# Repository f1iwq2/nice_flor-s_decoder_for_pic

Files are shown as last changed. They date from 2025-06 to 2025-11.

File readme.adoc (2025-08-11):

Nice flor-s / Came / CARDIN S449 / Somfy RTS / EV1527 /PT2260 remote decoder receiver for pic
=============================================================================================

Programme pic pour décoder les protocoles des télécommandes Nice-florS, CAME, EV1527, PT2260, Cardin S449 et Somfy RTS.
Fobloqs n'est pas terminé.
Le projet est composé d'un PIC 18F26K80 à 16 MHz (x4 par pll = 64 MHz)
L'eprom interne contient le fichier ki.bin ainsi que les télécommandes apprises.
L'eprom externe de 128Ko contient le fichier codes.bin
Le platine électronique est faite en Kicad, répertoire "telecommande".
Le logiciel est fait avec MPLAB XIDE, repertoire "telecommande.X".
Utiliser la directive francais pour basculer en français pour le dialogues UART (230400 bauds par défaut)
Came utilise le protocole radio OOK, code fixe.
NiceFlorS utilise le protocole radio ASK, code roulant.
Cardin utilise le protocole radio FSK, code roulant.
Utilisez le récepteur adéquat. Ne brancher qu'un seul récepteur sur la platine.
RXB6, RFM210LCF-A = ASK et OOK.
RXB15 = FSK
documentation dans le fichier pdf.

Taper ? [enter] dans le terminal pour afficher le menu.

Pic program to decode Nice-florS, CAME, EV1527, Cardin S449, and SOMFY RTS remote devices.
Fobloqs is not completed.
This project is made with a PIC 18F26K80 at 16 MHz (x4 with pll = 64 MHz)
Internal eprom contains the ki.bin file, and also learnt remotes.
External 128Kb eprom contains codes.bin file. 
The electronic board is made with Kicad, "telecommande" directory.
The software is made with MPLAB XIDE, "telecommande.X" directory.
Use english directive to switch to english UART dialogs (230400 bauds default).

CAME use OOK radio protocol. 
NiceFlorS use ASK radio protocol, rolling code.
Cardin use FSK radio protocol
Use the correct receiver. Plug only a single receiver on the board.
RXB6, RFM210LCF-A = ASK and OOK.
RXB15 = FSK
Documentation in pdf file.

Type in ? [enter] to display the menu.

The projet a été inspiré par :
This project was inspired from :
https://github.com/Jev1337/NiceFlor-Encoder

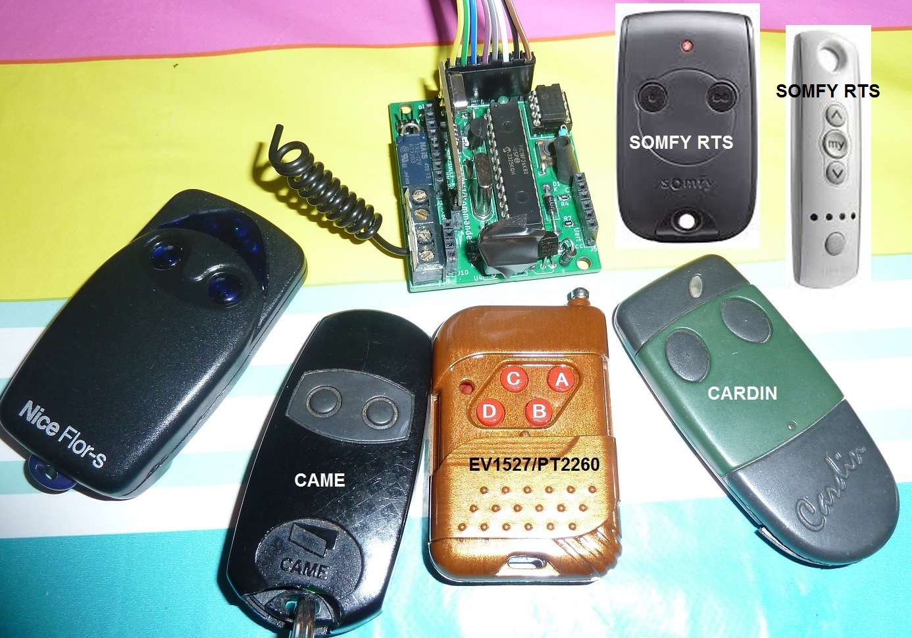
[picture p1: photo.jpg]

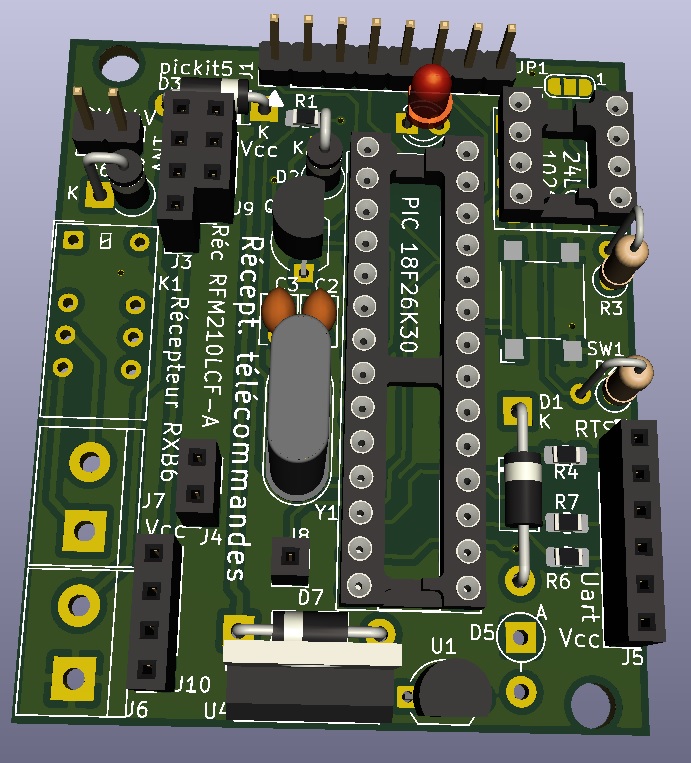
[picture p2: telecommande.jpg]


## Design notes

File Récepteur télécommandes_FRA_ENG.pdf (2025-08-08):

# Documentation carte récepteur télécommandes

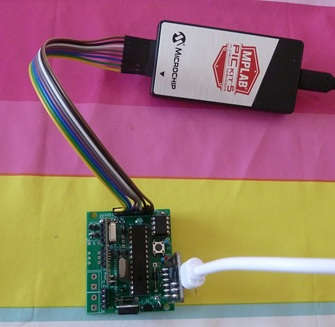
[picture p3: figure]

Cette carte est un décodeur multi protocoles de télécommandes. Elle supporte plusieurs types de récepteurs. Ne monter qu’un récepteur à la fois.

Protocoles OOK ASK (AM) supportés :
Nice Flor S
Came
Somfy RTS
EV/RT/FP 1527
SCT/PT 2260

Protocoles FM FSK:
Cardin S449.
Fobloqs non finalisé.

Carte en test avec le programmateur Pickit5 et le convertisseur USB/UART TTL pour le terminal.

En bas : carte avec le récepteur Dickert HQFM433P-50, et un câble d’adaptation. Rouge=5V, Noir=0V, Vert=Signal RX.

Cette carte décode les protocoles des télécommandes ci-dessus. Elle reçoit le récepteur depuis une carte d’adaptation enfichée sur un support, ou elle permet l’enfichage direct des récepteurs suivants :
Récepteurs testés :

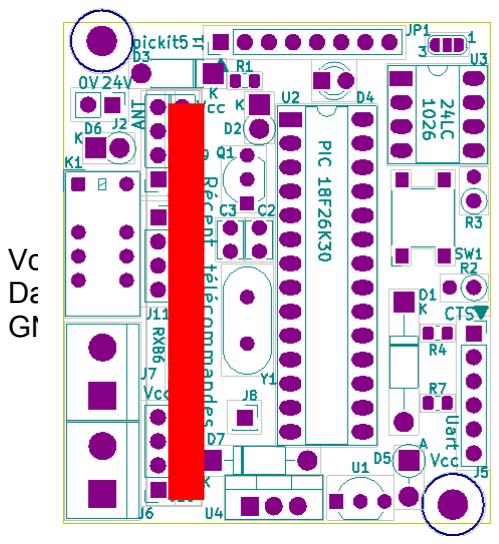
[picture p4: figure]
Data GND

ANT
GND
5V

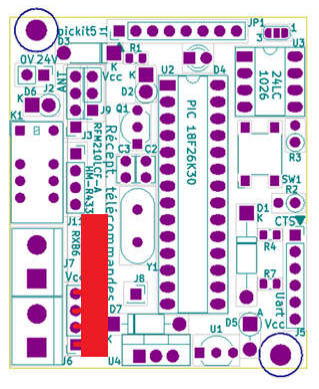
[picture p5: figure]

RX500
Sur connecteur J10
OOK et ASK
fonctionnel

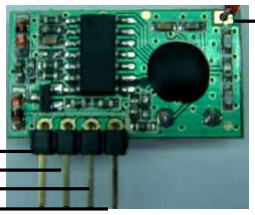
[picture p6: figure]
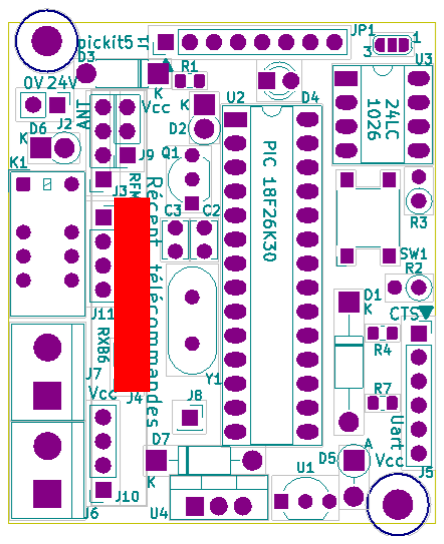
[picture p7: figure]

HM-R-433 sur connecteur J11

Nécessite un reset après mise sous tension
Non fonctionnel
Vcc
Data
GND
Enable

RFM210LCF-A
RXB8 (315 MHz)
sur connecteurs J4 et J9.
fonctionnel
ANT
GND

RXB6 sur connecteurs J3 et J10 OOK ASK
Fonctionnel

ANT

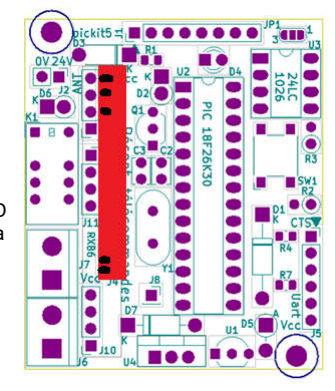
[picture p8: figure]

GND
Data
Vcc

Vcc

Dickert HQFM433P-50

Récepteur FM pour Cardin S449 ou Fobloqs. (35€). Nécessite un câble adaptateur.

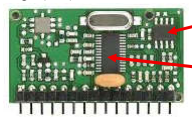
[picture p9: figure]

Nécessite une platine ou un câble d’adaptation.

## Gestion des télécommandes

Pour ajouter une télécommande, appuyer de façon impulsionnelle sur le bouton SW1, et activer une télécommande. La led clignote si la télécommande est reconnue, et le terminal affiche :

Télécommande xxxx ajoutée
Xxxx est le numéro de série renvoyé par la télécommande. Si la commande est déjà enregistrée, le terminal affiche :

Télécommande déjà stockée.

Pour supprimer toutes les télécommandes, appuyer et maintenir le bouton 2s, la led s’allume pendant 2s et s’éteint : toutes les télécommandes ont été supprimées. Le terminal affiche :

Effacement de toutes les télécommandes.

Lorsqu’une télécommande est reconnue, elle colle le relais K1 pendant 1 s. Le protocole des télécommandes est reconnu automatiquement.

Les télécommandes Somfy (certaines) et Cardin ont un bouton de programmation qui permettent de mémoriser un bouton d'une télécommande déja connue à un récepteur associé. Ce programme utilise cette fonction, mais prend en compte tout signal suivant se présentant et peut constituer une faille de sécurité. Cette fonctionnalité peut être dévalidée. Ceci est utile si le récepteur est encastré et on ne peut pas appuyer sur le bouton d'ajout d'une nouvelle télécommande (modeProg).

Schéma fait sous KICAD

Environnement logiciel sous MPLABX 6.25

Ressources internes :

1 Uart à 230240 bauds ou 9600 bauds (pour le transfert des fichiers EPROM en xmodem crc)
1 I2C pour l’eprom 24LC1026
Processeur PIC 18F26K80 à 64 MHz (quartz 16 Mhz ×4)
Le processeur est programmable via l’interface ICSP sur le connecteur J1 qui reçoit le programmateur pickit
5. Le montage peut être alimenté par le pickit.

1 2 3 4 5 6 7 8 9 10 12 13 15

1 : 5v
2,7,11 : GND
3 : Antenne
4,5,6 : NC
10,12,15 : à relier au 5v
13 : PDO (peak detector output) 14 : sortie données

393
EF625

TDA5210

## Utilisation du terminal

Pour utiliser le terminal, il faut brancher un convertisseur UART TTL 5V vers USB comme le WV21443 sur le connecteur J5. Il est connectable point à point. Le protocole RTS/CTS n’est pas utilisé.

WV21443
La vitesse par défaut du terminal est 230240 bauds.

Remote receiver for Nice FLOR-s / CAME / Somfy RTS F1IWQ 2025
** MENU **

?....Affiche ce menu
1....Change mode debug
2....UART9600/230400 bauds
3....Envoyer à l'eprom ext le fichier 128Ko de codes NiceFlorS (protocole Xmodem CRC) 4....Envoyer à l'eprom int le fichier 256o de ki NiceFlorS (protocole Xmodem CRC) 5....Affiche télégramme reçu de la télécommande
6....Affiche la dernière erreur
7....Octets recus par xmodem
8....Affiche les 200 premiers octets de l'EPROM externe 9....Affiche EPROM interne
A....Vérifie checksum eprom ext
B....Lit les 64Ko de l'eprom ext (long) par bloc de 128 octets C....Liste des télécommandes connues

1 : Change le niveau de debug de 0 à 3, pour un affichage plus ou moins détaillé.
2 : Bascule la valeur de l’UART à 230400 ou 9600 bauds. 9600 bauds est à utiliser pour les transferts xmodem. 3 : Envoie le fichier codes.bin à l’eprom externe en protocole xmodem crc (durée env 20mn)
4 : Envoie le fichier ki.bin à l’eprom interne en protocole xmodem crc.
Pour ces options 3 et 4, le caractère C est utilisé pour synchroniser le départ de xmodem. Vous avez 30 secondes pour sélectionner le fichier à envoyer. On peut utiliser teraterm par exemple.
L’écriture des eprom n’est a faire qu’une seule fois. Après l’écriture de l’eprom interne, il est conseillé de ponter les bornes 1 et 2 de JP1 pour éviter une écriture accidentelle.
5. Affiche le dernier télégramme reçu de la télécommande :

NbreBits=150 Protocole Cardin
1 | 33048 17 | 845 | 33 | 1553 | 49 | 1544 | 65 | 765 | 81 | 1233 | 97 | 497
2 | 1037 18 | 759 | 34 | 898 | 50 | 905 | 66 | 1627 | 82 | 383 | 98 | 270
3 | 601 | 19 | 854 | 35 | 1500 | 51 | 1492 | 67 | 805 | 83 | 862 | 99 | 447
4 | 952 | 20 | 752 | 36 | 934 | 52 | 941 | 68 | 1601 | 84 | 1067 100 | 429
5 | 688 | 21 | 859 | 37 | 1469 | 53 | 1464 | 69 | 2029 | 85 | 382 101 | 1011
6 | 888 | 22 | 749 | 38 | 962 | 54 | 965 | 70 | 330 | 86 | 155 102 | 174
7 | 741 | 23 | 859 | 39 | 1448 | 55 | 683 | 71 | 1264 | 87 | 1386 103 | 284
8 | 845 | 24 | 8792 | 40 | 986 | 56 | 1695 | 72 | 76 | 88 | 529 104 | 219
9 | 779 | 25 | 985 | 41 | 1421 | 57 | 748 | 73 | 838 | 89 | 204 105 | 288
10 | 817 | 26 | 1462 | 42 | 991 | 58 | 1643 | 74 | 686 | 90 | 222 106 | 226
11 | 805 | 27 | 930 | 43 | 1424 | 59 | 791 | 75 | 1076 | 91 | 184 107 | 906
12 | 794 | 28 | 1499 | 44 | 996 | 60 | 1607 | 76 | 1013 | 92 | 433 108 | 72
13 | 824 | 29 | 902 | 45 | 657 | 61 | 820 | 77 | 865 | 93 | 2105 109 | 739
14 | 775 | 30 | 1523 | 46 | 1713 | 62 | 1590 | 78 | 157 | 94 | 70 110 | 236
15 | 838 | 31 | 1634 | 47 | 735 | 63 | 1585 | 79 | 226 | 95 | 645 111 | 185
16 | 767 | 32 | 830 | 48 | 1650 | 64 | 868 | 80 | 535 | 96 | 333 112 | 254
Les bits sont en fait les durées des créneaux reçus du signal de la télécommande. La durée est à diviser par 2 pour les convertir en µs.
6. Affiche la dernière erreur du protocole xmodem crc.
7. Affiche les 128 octets reçus du protocole xmodem crc.
8. Affiche les 200 premiers octets de l’eprom externe pour vérification.

Vcc
GND
J5 | RX
| TX
| CTS
| RTS

9. Affiche le contenu de toute l’eprom interne.
A. Vérifie le checksum et le contenu de l’eprom externe.
B. Affiche le contenu de toute l’eprom externe (long).
C. Liste les télécommandes mémorisées.

# Remote control receiver board documentation

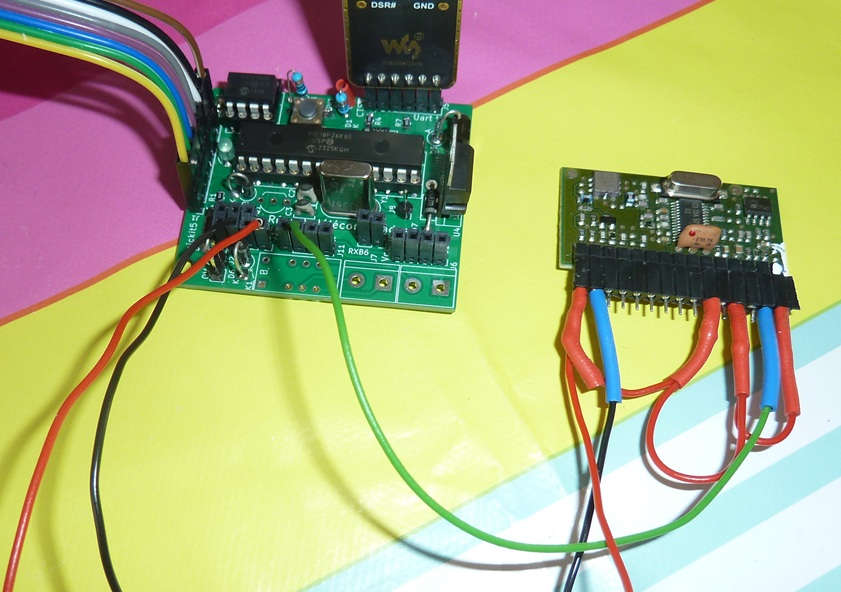
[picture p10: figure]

This board is a multi-protocol remote control decoder. It supports multiple receiver types. Only install one receiver at a time.

OOK ASK (AM) managed protocols :
Nice Flor S
Came
Somfy RTS
EV/RT/FP 1527
SCT/PT 2260

FM FSK protocols :
Cardin S449.
Fobloqs non finalisé.

Board testing with Pickit5 programmer and the USB/UART TTL converter for terminal.

Bottom: Board with Dickert HQFM433P-50 receiver, and adapter cable. Red=5V, Black=0V, Green=RX signal.

This board decodes the protocols of the above remote controls. It receives the bits stream from an adapter receiver board plugged into a support, or direct plugging if using the following receivers:

Tested receivers :

ANT
GND
5V

Dickert HQFM433P-50 (35€)

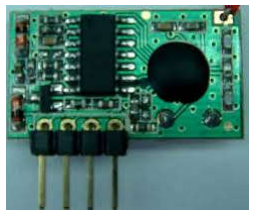
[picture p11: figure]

FM receiver for Cardin S449 or Fobloqs. Needs an adapter ribbon cable.

Electrical drawing with KICAD

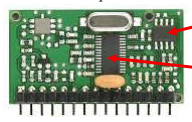
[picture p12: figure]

Software environment with MPLABX 6.25

1 Uart at 230240 bauds or 9600 bauds (for transferring EPROM files with xmodem crc) 1 I2C for eprom 24LC1026
Processor PIC 18F26K80 at 64 MHz (quartz 16 Mhz ×4)

1 2 3 4 5 6 7 8 9 10 12 13 15

1 : 5v
2,7,11 : GND
3 : Antenna
4,5,6 : NC
10,12,15 : needs a bridge to 5v 13 : PDO (peak detector output) 14 : data output

393
EF625

TDA5210

HM-R-433 on connector J11. Requires a reset after power on.

RFM210LCF-A
RXB8 (315 MHz)
on connector J4 and J9.

RXB6 on connectors J3 and J10

## Remote Control Management

To add a remote control, press and hold the SW1 button and press a remote control. The LED flashes if the remote control is recognized, and the terminal displays:

Remote control xxxx added
Xxxx is the serial number returned by the remote control. If the command is already registered, the terminal displays:

Remote control already stored.

To delete all remote controls, press and hold the button for 2 seconds. The LED lights up for 2 seconds and then turns off: all remote controls have been deleted. The terminal displays:

Deleting all remote controls.

When a remote control is recognized, the relay K1 is activated for 1 second. The remote control protocol is automatically recognized.

Some Somfy remotes and Cardin have a programming button that allows to memorize un known button remote to an already linked receiver. This program uses this feature, but also takes into account any subsequent signal that may appear, and might be a security failure. This feature can be disabled. This is useful if the receiver is recessed and the button to add a new remote control can't be pressed.

## Using the Terminal

To use the terminal, you must connect a 5V UART TTL to USB converter such as the WV21443 to the J5 connector. It is a straight connector point-to-point. The RTS/CTS protocol is not used.

WV21443
The terminal default baud rate is 230240.

Remote receiver for Nice FLOR-s / CAME / Somfy RTS F1IWQ 2025
** MENU **

?....Display this menu
1....Change debug mode
2....UART 9600/230400 baud
3....Send the 128KB NiceFlorS code file to the external EPROM (Xmodem CRC protocol) 4....Send the 256KB NiceFlorS code file to the internal EPROM (Xmodem CRC protocol) 5....Display telegram received from the remote control
6....Display the last error
7....Bytes received by Xmodem
8....Display the first 200 bytes of the external EPROM 9....Display the internal EPROM
A....Verify the external EPROM checksum
B....Read the 64KB of the ext (long) EPROM in 128-byte blocks C....List of known remote controls

1: Changes the debug level from 0 to 3, for a more or less detailed display.
2: Toggles the UART value to 230400 or 9600 baud. 9600 baud is to be used for xmodem transfers.

Vcc
GND
J5 | RX
| TX
| CTS
| RTS

3: Sends the codes.bin file to the external EPROM using the xmodem crc protocol (takes approximately 20 minutes).
4: Sends the ki.bin file to the internal EPROM using the xmodem crc protocol.
For options 3 and 4, the C character is used to synchronize the xmodem start. You have 30 seconds to select the file to send. You can use teraterm, for example.
Writing the EPROMs only needs to be done once. After writing the internal EPROM, it is recommended to bridge terminals 1 and 2 of JP1 to prevent accidental writing.
5. Displays the last telegram received from the remote control:

NbreBits=150 Protocole Cardin
1 | 33048 17 | 845 | 33 | 1553 | 49 | 1544 | 65 | 765 | 81 | 1233 | 97 | 497
2 | 1037 18 | 759 | 34 | 898 | 50 | 905 | 66 | 1627 | 82 | 383 | 98 | 270
3 | 601 | 19 | 854 | 35 | 1500 | 51 | 1492 | 67 | 805 | 83 | 862 | 99 | 447
4 | 952 | 20 | 752 | 36 | 934 | 52 | 941 | 68 | 1601 | 84 | 1067 100 | 429
5 | 688 | 21 | 859 | 37 | 1469 | 53 | 1464 | 69 | 2029 | 85 | 382 101 | 1011
6 | 888 | 22 | 749 | 38 | 962 | 54 | 965 | 70 | 330 | 86 | 155 102 | 174
7 | 741 | 23 | 859 | 39 | 1448 | 55 | 683 | 71 | 1264 | 87 | 1386 103 | 284
8 | 845 | 24 | 8792 | 40 | 986 | 56 | 1695 | 72 | 76 | 88 | 529 104 | 219
9 | 779 | 25 | 985 | 41 | 1421 | 57 | 748 | 73 | 838 | 89 | 204 105 | 288
10 | 817 | 26 | 1462 | 42 | 991 | 58 | 1643 | 74 | 686 | 90 | 222 106 | 226
11 | 805 | 27 | 930 | 43 | 1424 | 59 | 791 | 75 | 1076 | 91 | 184 107 | 906
12 | 794 | 28 | 1499 | 44 | 996 | 60 | 1607 | 76 | 1013 | 92 | 433 108 | 72
13 | 824 | 29 | 902 | 45 | 657 | 61 | 820 | 77 | 865 | 93 | 2105 109 | 739
14 | 775 | 30 | 1523 | 46 | 1713 | 62 | 1590 | 78 | 157 | 94 | 70 110 | 236
15 | 838 | 31 | 1634 | 47 | 735 | 63 | 1585 | 79 | 226 | 95 | 645 111 | 185
16 | 767 | 32 | 830 | 48 | 1650 | 64 | 868 | 80 | 535 | 96 | 333 112 | 254

The bits are actually the durations of the received signal slots from the remote control. Divide the duration by 2 to convert them to µs.
6. Displays the last error of the xmodem crc protocol.
7. Displays the 128 bytes received from the xmodem crc protocol.
8. Displays the first 200 bytes of the external EPROM for verification.
9. Displays the contents of the entire internal EPROM.
A. Verifies the checksum and contents of the external EPROM.
B. Displays the contents of the entire external EPROM (takes long time).
C. Lists the stored remote controls.

## Chronogrammes

### Flobloqs (FM-FSK) 433,920 MHz

Séquence complète:

3 bits silence de 3400µs | Récepteur utilisé : Dickert HQFM433P-50
19 bits de sync
1 start bit de 1570µs
Codage des bits de données : Keyloq. Bit0=400µs Bit1=800µs.
Présence éventuelle dans les données d’un extra bit de 1200µs à une distance variable du start bit, ou c’est un stop bit.
L’algorithme de décodage est plus ou moins connu mais pas la clé.
1 stop bit de 1200µs
3 bits de silence de 3400µs

### Cardin S449 (FM-FSK) 433,920 MHz

1 créneau de silence de 16520µs | Récepteur utilisé : Dickert HQFM433P-50
11 ou 12 bits de sync
1 créneau start de 4000µs
Codage des 64 bits de données : Keyloq. Bit1=390/785µs Bit0=785/390µs
Le LSB est envoyé en premier. Le numéro de série n’est pas crypté de même que les boutons.

### NiceFlorS (AM-ASK) 433,920 MHz

1 créneau de silence de 18888µs
1 bit de start 1500µs
Codage des 52 bits de données : spécifique. Bit0=500/1000µs Bit1=1000/500µs 1 créneau stop de 1500µs

### CAME (AM-ASK) 433,920 MHz

1 créneau silence de 14845µs
Codage fixe des 12 bits de données : Bit0=320/640µs Bit1=640/320µs
Silence1 | Silence2 Silence3 | 19 sync | start

56 bits de données

Silence | 11 ou 12 sync | start

64 bits de données

S1 | S2 | S3 | 19 sync | start | Bits de données | stop 3xfin
Silence | start | stop

Silence

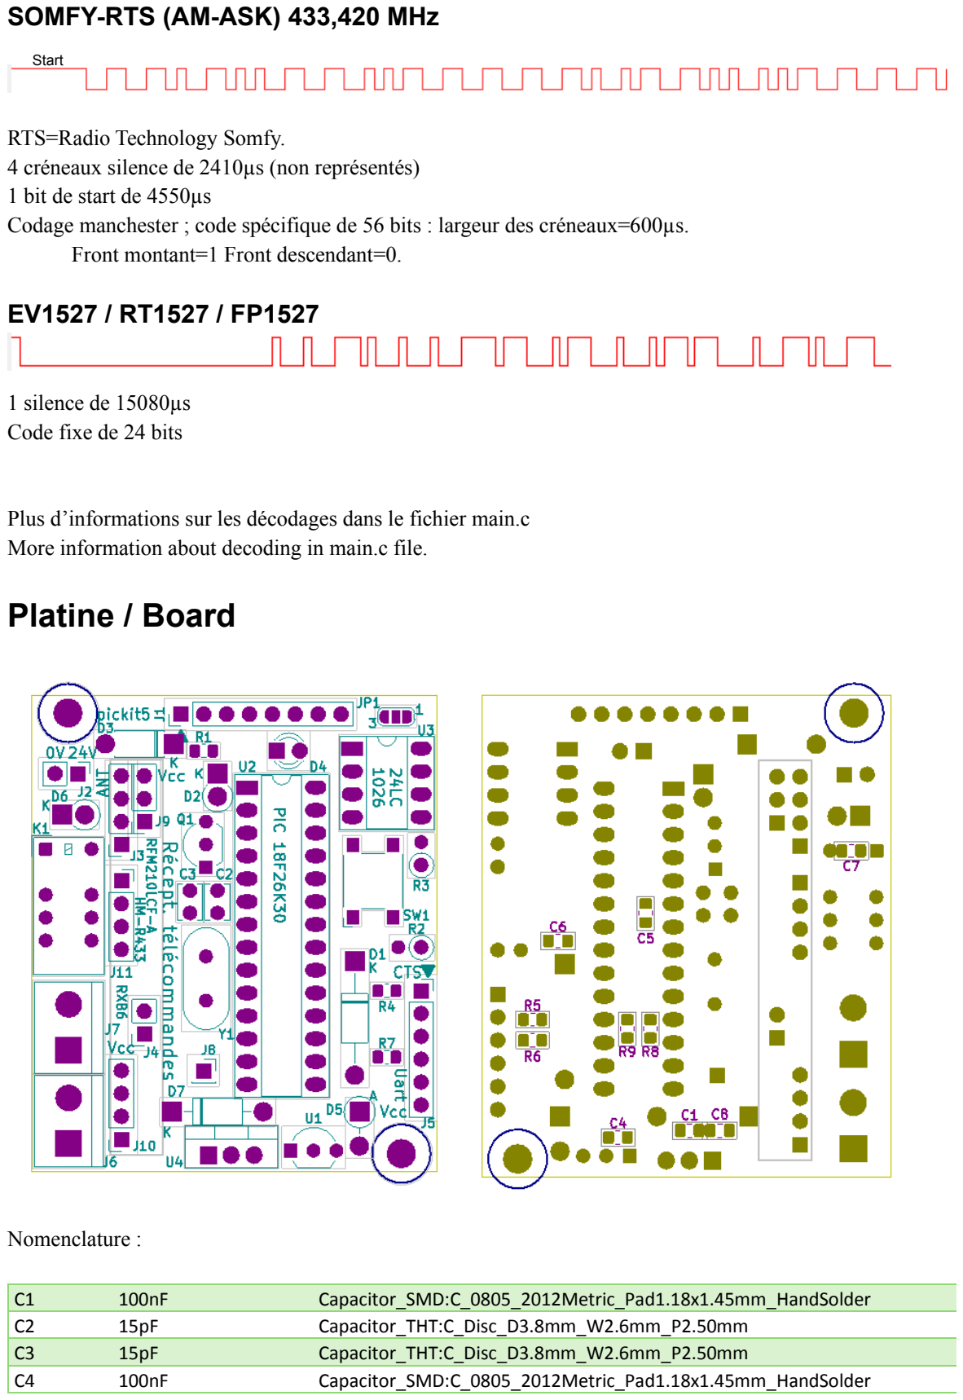
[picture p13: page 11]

### SOMFY-RTS (AM-ASK) 433,420 MHz

RTS=Radio Technology Somfy.
4 créneaux silence de 2410µs (non représentés)
1 bit de start de 4550µs
Codage manchester ; code spécifique de 56 bits : largeur des créneaux=600µs. Front montant=1 Front descendant=0.

### EV1527 / RT1527 / FP1527

1 silence de 15080µs
Code fixe de 24 bits

Plus d’informations sur les décodages dans le fichier main.c More information about decoding in main.c file.

## Platine / Board

Nomenclature :

C1 | 100nF | Capacitor_SMD:C_0805_2012Metric_Pad1.18x1.45mm_HandSolder
C2 | 15pF | Capacitor_THT:C_Disc_D3.8mm_W2.6mm_P2.50mm
C3 | 15pF | Capacitor_THT:C_Disc_D3.8mm_W2.6mm_P2.50mm
C4 | 100nF | Capacitor_SMD:C_0805_2012Metric_Pad1.18x1.45mm_HandSolder

Start

C5 | 100nF | Capacitor_SMD:C_0805_2012Metric_Pad1.18x1.45mm_HandSolder
C6 | 100nF | Capacitor_SMD:C_0805_2012Metric_Pad1.18x1.45mm_HandSolder
C7 | 100nF | Capacitor_SMD:C_0805_2012Metric_Pad1.18x1.45mm_HandSolder
C8 | 100nF | Capacitor_SMD:C_0805_2012Metric_Pad1.18x1.45mm_HandSolder
D1 | 1N4004 | Diode_THT:D_DO-41_SOD81_P12.70mm_Horizontal
D2 | 1N4004 | Diode_THT:D_DO-41_SOD81_P2.54mm_Vertical_KathodeUp
D3 | 1N4004 | Diode_THT:D_DO-41_SOD81_P7.62mm_Horizontal
D4 | LED | LED_THT:LED_D3.0mm
D5 | 1N4004 | Diode_THT:D_DO-41_SOD81_P3.81mm_Vertical_KathodeUp
D6 | 1N4004 | Diode_THT:D_DO-41_SOD81_P2.54mm_Vertical_KathodeUp
D7 | 1N4004 | Diode_THT:D_DO-41_SOD81_P10.16mm_Horizontal
H1 | MountingHole | MountingHole:MountingHole_3.2mm_M3
H2 | MountingHole | MountingHole:MountingHole_3.2mm_M3
J1 | Conn_01x08_Male | Connector_PinHeader_2.54mm:PinHeader_1x08_P2.54mm_Vertical
J10 | Conn_01x04_Female | Connector_PinSocket_2.54mm:PinSocket_1x04_P2.54mm_Vertical
J11 | Conn_01x04_Female | Connector_PinSocket_2.54mm:PinSocket_1x04_P2.54mm_Vertical
J2 | Conn_01x02_Male | Connector_PinHeader_2.54mm:PinHeader_1x02_P2.54mm_Vertical
J3 | Conn_01x04_Female | Connector_PinSocket_2.54mm:PinSocket_1x04_P2.54mm_Vertical
J4 | Conn_01x02_Female | Connector_PinSocket_2.54mm:PinSocket_1x02_P2.54mm_Vertical
J5 | Conn_01x06_Male | Connector_PinSocket_2.54mm:PinSocket_1x06_P2.54mm_Vertical
J6 | Screw_Terminal_01x0
| 2 | TerminalBlock:TerminalBlock_bornier-2_P5.08mm
J7 | Screw_Terminal_01x0
| 2 | TerminalBlock:TerminalBlock_bornier-2_P5.08mm
J8 | Conn_01x01_Male | Connector_PinSocket_2.54mm:PinSocket_1x01_P2.54mm_Vertical
J9 | Conn_01x03_Female | Connector_PinSocket_2.54mm:PinSocket_1x03_P2.54mm_Vertical
JP1 | SolderJumper_3_Open | Jumper:SolderJumper-
| | 3_P1.3mm_Open_RoundedPad1.0x1.5mm_NumberLabels
K1 | ATX203 | Relay_THT:Relay_DPDT_Kemet_EC2 12V coil bobine 12V
Q1 | BS170 | Package_TO_SOT_THT:TO-92_Inline_Wide
R1 | 330 | Resistor_SMD:R_0805_2012Metric_Pad1.20x1.40mm_HandSolder
R2 | 330 | Resistor_THT:R_Axial_DIN0207_L6.3mm_D2.5mm_P2.54mm_Vertical
R3 | 330 | Resistor_THT:R_Axial_DIN0207_L6.3mm_D2.5mm_P2.54mm_Vertical
R4 | 90 | Resistor_SMD:R_0805_2012Metric_Pad1.20x1.40mm_HandSolder
R5 | 90 | Resistor_SMD:R_0805_2012Metric_Pad1.20x1.40mm_HandSolder
R6 | 90 | Resistor_SMD:R_0805_2012Metric_Pad1.20x1.40mm_HandSolder
R7 | 90 | Resistor_SMD:R_0805_2012Metric_Pad1.20x1.40mm_HandSolder
R8 | 8,2k | Resistor_SMD:R_0805_2012Metric_Pad1.20x1.40mm_HandSolder
R9 | 8,2k | Resistor_SMD:R_0805_2012Metric_Pad1.20x1.40mm_HandSolder
Reference | Value | Footprint
SW1 | SW_MEC_5E | Button_Switch_SMD:SW_SPST_Omron_B3FS-101xP
U1 | L78L05_TO92 | Package_TO_SOT_THT:TO-92_Inline_Wide
U2 | PIC18F26K80_ISP | Package_DIP:DIP-28_W7.62mm_Socket_LongPads
U3 | 24LC1026-I_P | Package_DIP:DIP-8_W7.62mm_Socket_LongPads
U4 | 7812 | Package_TO_SOT_THT:TO-220-3_Vertical
Y1 | Crystal 16MHz | Crystal:Crystal_HC18-U_Vertical

## Github contains

https://github.com/f1iwq2/nice_flor-s_decoder_for_pic

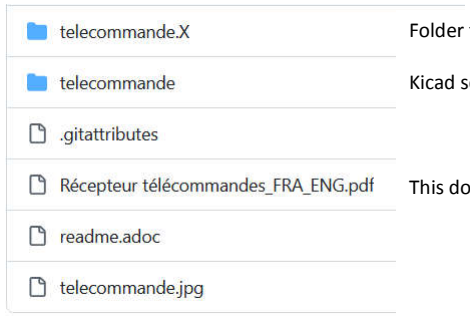
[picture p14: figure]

Folder for PIC soware. Use MPLABX. Main.c is the main.

Kicad schemacs drawings. Sub dir contains gerber files.

This documentaon.

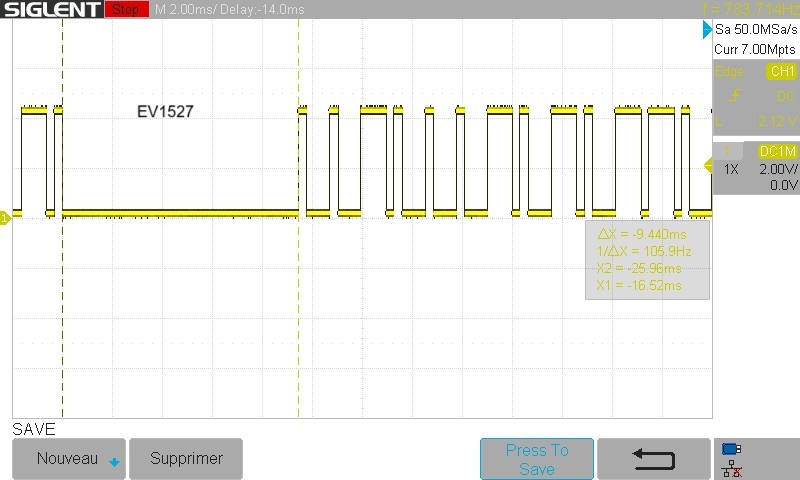
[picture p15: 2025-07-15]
telecommande.X/EV1527-1.jpg

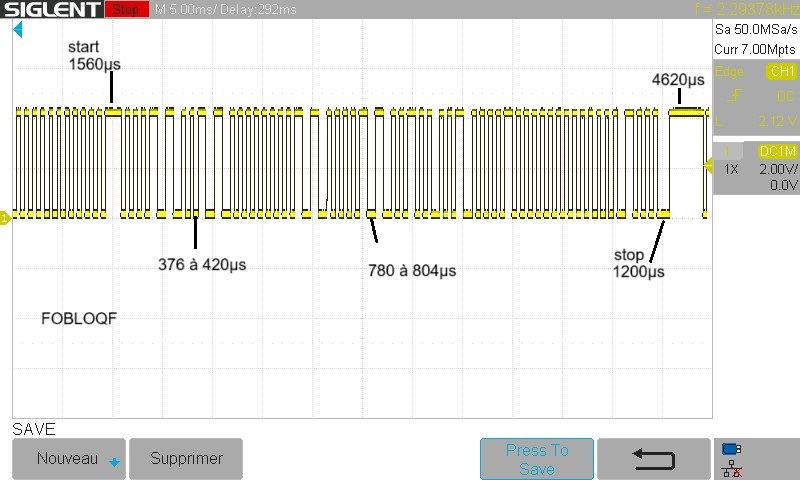
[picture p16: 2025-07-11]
telecommande.X/fobloqf2.jpg

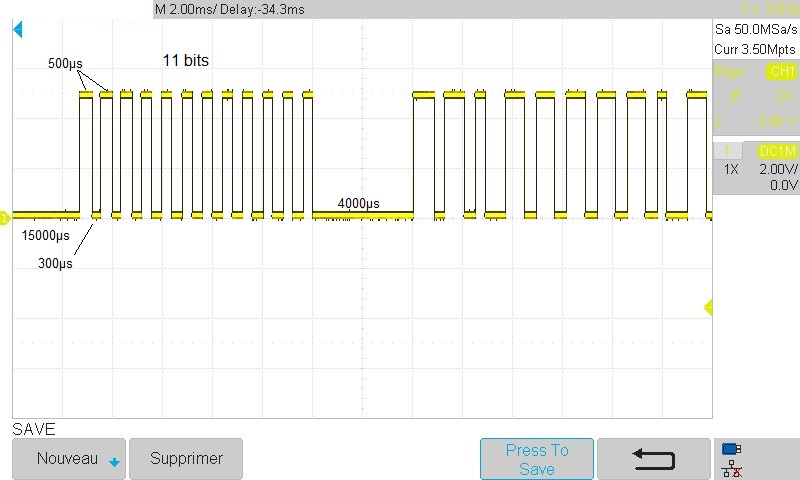
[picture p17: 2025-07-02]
telecommande.X/cardin_debut.jpg

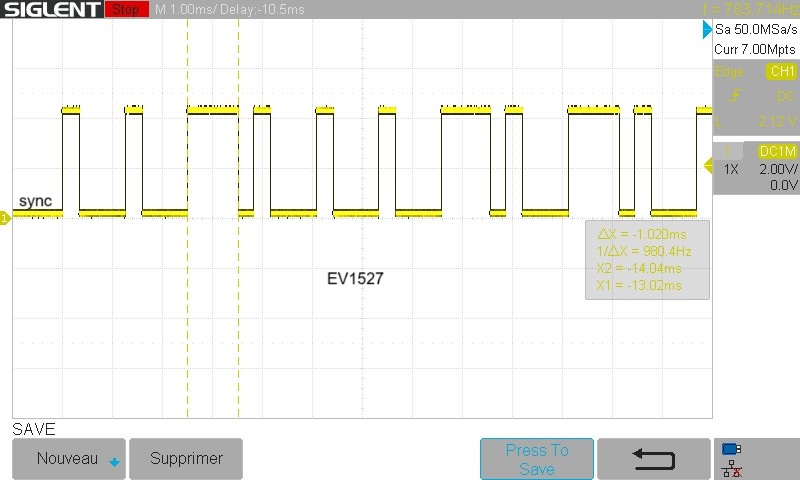
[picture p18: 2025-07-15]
telecommande.X/EV1527-2.jpg

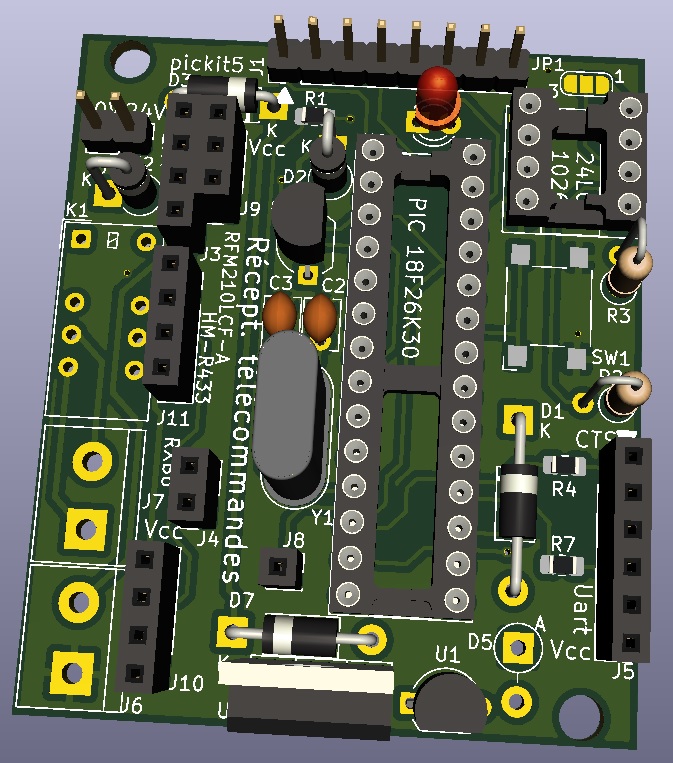
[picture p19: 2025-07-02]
telecommande/telecommande.jpg

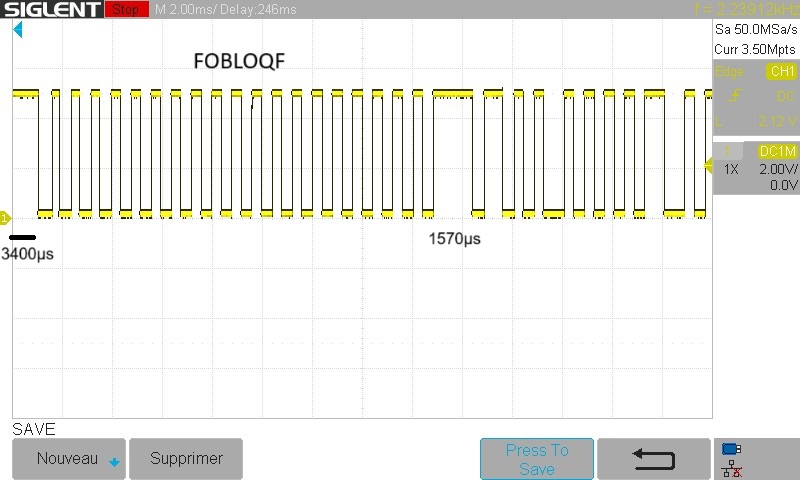
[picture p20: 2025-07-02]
telecommande.X/fobloqf.jpg

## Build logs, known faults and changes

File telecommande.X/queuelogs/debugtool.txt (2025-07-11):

247 1751989909826 GEN4_CONNECT_DIAGNOSTICS:MPLABCommTool is null

247 1751989909826 GEN4_TO_CONTROLLER_LOG:GEN4_CONNECT_INT_LOG_PIC18F26K80 Pre:GetFirmwareInfo
247 1751989909826 GEN4_TO_CONTROLLER_LOG:GEN4_CONNECT_INT_LOG_PIC18F26K80 Payload
247 1751989909826 GEN4_TO_CONTROLLER_LOG:GEN4_CONNECT_INT_LOG_PIC18F26K80 null
247 1751989909826 GEN4_TO_CONTROLLER_LOG:GEN4_CONNECT_INT_LOG_PIC18F26K80 Payload End
247 1751989909827 XXXX 1751989909827, Thread 247: com.Send returned false 
247 1751989909827 XXXX 1751989909827, Thread 247: execCommand: exception after writeSideChanel null 
247 1751989909828 GEN4_CONNECT_DIAGNOSTICS:Removing plug and play observer com.microchip.mplab.mdbcore.RI4Tool.RI4ToolBase$RI4PlugNPlayObserver@26d3e0c3
247 1751989909828 GEN4_CONNECT_DIAGNOSTICS:Begin PlugNPlayObservers list dump:
247 1751989909828 GEN4_CONNECT_DIAGNOSTICS:End PlugNPlayObservers list dump:
247 1751989909881 GEN4_CONNECT_DIAGNOSTICS:Calling RIDbgToolCom.Disconnect
247 1751989909881 GEN4_CONNECT_DIAGNOSTICS:Calling MPLABCommTool.Detach to remove tool from plug and play list
247 1751989909881 GEN4_CONNECT_DIAGNOSTICS:Calling RIDbgToolCom.DisconnectFromMPlabComm
247 1751989909881 GEN4_CONNECT_DIAGNOSTICS:Calling MPLABCommTool.Disconnect
269 1751989937830 GEN4_CONNECT_DIAGNOSTICS:MPLABCommTool is NOT null
269 1751989937830 GEN4_CONNECT_DIAGNOSTICS:AttachedToolPID = 9036, AttachedToolVID = 4d8
269 1751989937830 GEN4_CONNECT_DIAGNOSTICS:transport type = USB
269 1751989937830 GEN4_CONNECT_DIAGNOSTICS:AttachedToolPID = 9036, AttachedToolVID = 4d8
269 1751989937836 com.microchip.mplab.mdbcore.RealICETool.RIDbgToolCom
269 1751989937836 GEN4_CONNECT_DIAGNOSTICS:Before MPLABCommTool.Connect()
269 1751989937837 GEN4_CONNECT_DIAGNOSTICS:After MPLABCommTool.Connect()
269 1751989937837 GEN4_CONNECT_DIAGNOSTICS:Adding new plug and play observer com.microchip.mplab.mdbcore.RI4Tool.RI4ToolBase$RI4PlugNPlayObserver@1160412d
269 1751989937837 GEN4_CONNECT_DIAGNOSTICS:Begin PlugNPlayObservers list dump:
269 1751989937837 GEN4_CONNECT_DIAGNOSTICS:com.microchip.mplab.mdbcore.RI4Tool.RI4ToolBase$RI4PlugNPlayObserver@1160412d
269 1751989937837 GEN4_CONNECT_DIAGNOSTICS:End PlugNPlayObservers list dump:
269 1751989937837 GEN4_CONNECT_DIAGNOSTICS:Registering for alternate PNP notifications. CommPnPCriteria.cPIDList = [9035], CommPnPCriteria.cSerialNumber = 020026702ryn032916

269 1751989937888 GEN4_TO_CONTROLLER_LOG:GEN4_INIT_INT_LOG_PIC18F26K80 Pre:init
269 1751989937888 GEN4_TO_CONTROLLER_LOG:GEN4_INIT_INT_LOG_PIC18F26K80 Payload
269 1751989937888 GEN4_TO_CONTROLLER_LOG:GEN4_INIT_INT_LOG_PIC18F26K80 DeviceInfo: Values:
269 1751989937888 GEN4_TO_CONTROLLER_LOG:GEN4_INIT_INT_LOG_PIC18F26K80 DeviceInfo: pcAddress = 00000ff9, Vpp = 9,00, useRowEraseIfVoltageIsLow = true, voltageBelowWhichUseRowErase = 2,70, deviceName = PIC18F26K80, programmerType = PIC18F
269 1751989937888 GEN4_TO_CONTROLLER_LOG:GEN4_INIT_INT_LOG_PIC18F26K80 DeviceInfo: MemInfo values:
269 1751989937888 GEN4_TO_CONTROLLER_LOG:GEN4_INIT_INT_LOG_PIC18F26K80 DeviceInfo: mask = ffff, exists = true, startAddr = 00000000, endAddr = 0000ffff, rowSize = 0040, rowEraseSize = 0040, addrInc = 0002, widthProgram = 0002
269 1751989937888 GEN4_TO_CONTROLLER_LOG:GEN4_INIT_INT_LOG_PIC18F26K80 DeviceInfo: mask = 00ff, exists = true, startAddr = 00300000, endAddr = 0030000d, rowSize = 0001, rowEraseSize = 0000, addrInc = 0001, widthProgram = 0001
269 1751989937888 GEN4_TO_CONTROLLER_LOG:GEN4_INIT_INT_LOG_PIC18F26K80 DeviceInfo: mask = 0000, exists = false, startAddr = 00000000, endAddr = 00000000, rowSize = 0000, rowEraseSize = 0040, addrInc = 0000, widthProgram = 0000
269 1751989937888 GEN4_TO_CONTROLLER_LOG:GEN4_INIT_INT_LOG_PIC18F26K80 DeviceInfo: mask = 00ff, exists = true, startAddr = 00000000, endAddr = 000003ff, rowSize = 0002, rowEraseSize = 0000, addrInc = 0001, widthProgram = 0001
269 1751989937888 GEN4_TO_CONTROLLER_LOG:GEN4_INIT_INT_LOG_PIC18F26K80 DeviceInfo: mask = 00ff, exists = true, startAddr = 00200000, endAddr = 00200007, rowSize = 0001, rowEraseSize = 0000, addrInc = 0001, widthProgram = 0001
269 1751989937888 GEN4_TO_CONTROLLER_LOG:GEN4_INIT_INT_LOG_PIC18F26K80 DeviceInfo: mask = ffff, exists = true, startAddr = 00200000, endAddr = 002003ff, rowSize = 0040, rowEraseSize = 0040, addrInc = 0002, widthProgram = 0002
269 1751989937888 GEN4_TO_CONTROLLER_LOG:GEN4_INIT_INT_LOG_PIC18F26K80 DeviceInfo: mask = 0000, exists = false, startAddr = 00000000, endAddr = 00000000, rowSize = 0000, rowEraseSize = 0000, addrInc = 0001, widthProgram = 0001
269 1751989937888 GEN4_TO_CONTROLLER_LOG:GEN4_INIT_INT_LOG_PIC18F26K80 DeviceInfo: mask = 0000, exists = false, startAddr = 00000000, endAddr = 00000000, rowSize = 0000, rowEraseSize = 0000, addrInc = 0000, widthProgram = 0000
269 1751989937888 GEN4_TO_CONTROLLER_LOG:GEN4_INIT_INT_LOG_PIC18F26K80 DeviceInfo: mask = 0000, exists = false, startAddr = 00000000, endAddr = 00000000, rowSize = 0000, rowEraseSize = 0000, addrInc = 0000, widthProgram = 0000
269 1751989937888 GEN4_TO_CONTROLLER_LOG:GEN4_INIT_INT_LOG_PIC18F26K80 DeviceInfo: mask = 0000, exists = false, startAddr = 00000000, endAddr = 00000000, rowSize = 0000, rowEraseSize = 0000, addrInc = 0000, widthProgram = 0000
269 1751989937888 GEN4_TO_CONTROLLER_LOG:GEN4_INIT_INT_LOG_PIC18F26K80 DeviceInfo: mask = 0000, exists = false, startAddr = 00000000, endAddr = 00000000, rowSize = 0000, rowEraseSize = 0000, addrInc = 0001, widthProgram = 0001
269 1751989937888 GEN4_TO_CONTROLLER_LOG:GEN4_INIT_INT_LOG_PIC18F26K80 DeviceInfo: mask = 0000, exists = false, startAddr = 00000000, endAddr = 00000000, rowSize = 0000, rowEraseSize = 0000, addrInc = 0001, widthProgram = 0001
269 1751989937888 GEN4_TO_CONTROLLER_LOG:GEN4_INIT_INT_LOG_PIC18F26K80 DeviceInfo: mask = 0000, exists = false, startAddr = 00000000, endAddr = 00000000, rowSize = 0000, rowEraseSize = 0000, addrInc = 0000, widthProgram = 0000
269 1751989937888 GEN4_TO_CONTROLLER_LOG:GEN4_INIT_INT_LOG_PIC18F26K80 DeviceInfo: mask = 0000, exists = false, startAddr = 00000000, endAddr = 00000000, rowSize = 0000, rowEraseSize = 0000, addrInc = 0000, widthProgram = 0000
269 1751989937888 GEN4_TO_CONTROLLER_LOG:GEN4_INIT_INT_LOG_PIC18F26K80 DeviceInfo: mask = 0000, exists = false, startAddr = 00000000, endAddr = 00000000, rowSize = 0000, rowEraseSize = 0000, addrInc = 0000, widthProgram = 0000
269 1751989937888 GEN4_TO_CONTROLLER_LOG:GEN4_INIT_INT_LOG_PIC18F26K80 DeviceInfo: mask = 0000, exists = false, startAddr = 00000000, endAddr = 00000000, rowSize = 0000, rowEraseSize = 0000, addrInc = 0000, widthProgram = 0000
269 1751989937888 GEN4_TO_CONTROLLER_LOG:GEN4_INIT_INT_LOG_PIC18F26K80 DeviceInfo: mask = 7fffffff, exists = true, startAddr = 003ffffe, endAddr = 003fffff, rowSize = 0001, rowEraseSize = 0000, addrInc = 0001, widthProgram = 0001
269 1751989937888 GEN4_TO_CONTROLLER_LOG:GEN4_INIT_INT_LOG_PIC18F26K80 DeviceInfo: mask = 0000, exists = false, startAddr = 00000000, endAddr = 00000000, rowSize = 0000, rowEraseSize = 0000, addrInc = 0000, widthProgram = 0000
269 1751989937888 GEN4_TO_CONTROLLER_LOG:GEN4_INIT_INT_LOG_PIC18F26K80 DeviceInfo: mask = 0000, exists = false, startAddr = 00000000, endAddr = 00000000, rowSize = 0000, rowEraseSize = 0000, addrInc = 0000, widthProgram = 0000
269 1751989937888 GEN4_TO_CONTROLLER_LOG:GEN4_INIT_INT_LOG_PIC18F26K80 DeviceInfo: mask = 0000, exists = false, startAddr = 00000000, endAddr = 00000000, rowSize = 0000, rowEraseSize = 0000, addrInc = 0000, widthProgram = 0000
269 1751989937888 GEN4_TO_CONTROLLER_LOG:GEN4_INIT_INT_LOG_PIC18F26K80 DeviceInfo: mask = 0000, exists = false, startAddr = 00000000, endAddr = 00000000, rowSize = 0000, rowEraseSize = 0000, addrInc = 0000, widthProgram = 0000
269 1751989937888 GEN4_TO_CONTROLLER_LOG:GEN4_INIT_INT_LOG_PIC18F26K80 DeviceInfo: mask = 0000, exists = false, startAddr = 00000000, endAddr = 00000000, rowSize = 0000, rowEraseSize = 0000, addrInc = 0000, widthProgram = 0000
269 1751989937889 GEN4_TO_CONTROLLER_LOG:GEN4_INIT_INT_LOG_PIC18F26K80 DeviceInfo: mask = 0000, exists = false, startAddr = 00000000, endAddr = 00000000, rowSize = 0000, rowEraseSize = 0000, addrInc = 0000, widthProgram = 0000
269 1751989937889 GEN4_TO_CONTROLLER_LOG:GEN4_INIT_INT_LOG_PIC18F26K80 DeviceInfo: CfgRequiredBitsMask Values:
269 1751989937889 GEN4_TO_CONTROLLER_LOG:GEN4_INIT_INT_LOG_PIC18F26K80 Address = 00300000, Mask = 0000005d
269 1751989937889 GEN4_TO_CONTROLLER_LOG:GEN4_INIT_INT_LOG_PIC18F26K80 Address = 00300001, Mask = 000000df
269 1751989937889 GEN4_TO_CONTROLLER_LOG:GEN4_INIT_INT_LOG_PIC18F26K80 Address = 00300002, Mask = 0000007f
269 1751989937889 GEN4_TO_CONTROLLER_LOG:GEN4_INIT_INT_LOG_PIC18F26K80 Address = 00300003, Mask = 0000007f
269 1751989937889 GEN4_TO_CONTROLLER_LOG:GEN4_INIT_INT_LOG_PIC18F26K80 Address = 00300005, Mask = 00000089
269 1751989937889 GEN4_TO_CONTROLLER_LOG:GEN4_INIT_INT_LOG_PIC18F26K80 Address = 00300006, Mask = 00000011
269 1751989937889 GEN4_TO_CONTROLLER_LOG:GEN4_INIT_INT_LOG_PIC18F26K80 Address = 00300008, Mask = 0000000f
269 1751989937889 GEN4_TO_CONTROLLER_LOG:GEN4_INIT_INT_LOG_PIC18F26K80 Address = 00300009, Mask = 000000c0
269 1751989937889 GEN4_TO_CONTROLLER_LOG:GEN4_INIT_INT_LOG_PIC18F26K80 Address = 0030000a, Mask = 0000000f
269 1751989937889 GEN4_TO_CONTROLLER_LOG:GEN4_INIT_INT_LOG_PIC18F26K80 Address = 0030000b, Mask = 000000e0
269 1751989937889 GEN4_TO_CONTROLLER_LOG:GEN4_INIT_INT_LOG_PIC18F26K80 Address = 0030000c, Mask = 0000000f
269 1751989937889 GEN4_TO_CONTROLLER_LOG:GEN4_INIT_INT_LOG_PIC18F26K80 Address = 0030000d, Mask = 00000040
269 1751989937889 GEN4_TO_CONTROLLER_LOG:GEN4_INIT_INT_LOG_PIC18F26K80 BasicInfo: Values:
269 1751989937889 GEN4_TO_CONTROLLER_LOG:GEN4_INIT_INT_LOG_PIC18F26K80 BasicInfo: InputStream = com.microchip.mplab.libs.toolpacksupport.EquatableFileInputStream@b9753464, ToolFlavor = PIC32C
269 1751989937889 GEN4_TO_CONTROLLER_LOG:GEN4_INIT_INT_LOG_PIC18F26K80 Payload End
269 1751989937889 GEN4_TO_CONTROLLER_LOG:GEN4_INIT_INT_LOG_PIC18F26K80 Post:init
269 1751989937889 GEN4_TO_CONTROLLER_LOG:GEN4_INIT_INT_LOG_PIC18F26K80 Return Value
269 1751989937889 GEN4_TO_CONTROLLER_LOG:GEN4_INIT_INT_LOG_PIC18F26K80 none
269 1751989937889 GEN4_TO_CONTROLLER_LOG:GEN4_INIT_INT_LOG_PIC18F26K80 Return End

269 1751989937890 GEN4_TO_CONTROLLER_LOG:GEN4_INIT_INT_LOG_PIC18F26K80 Pre:GetInterfaceProvider
269 1751989937890 GEN4_TO_CONTROLLER_LOG:GEN4_INIT_INT_LOG_PIC18F26K80 Payload
269 1751989937890 GEN4_TO_CONTROLLER_LOG:GEN4_INIT_INT_LOG_PIC18F26K80 RI4DebugInterface
269 1751989937890 GEN4_TO_CONTROLLER_LOG:GEN4_INIT_INT_LOG_PIC18F26K80 Payload End
269 1751989937890 GEN4_TO_CONTROLLER_LOG:GEN4_INIT_INT_LOG_PIC18F26K80 Post:GetInterfaceProvider
269 1751989937890 GEN4_TO_CONTROLLER_LOG:GEN4_INIT_INT_LOG_PIC18F26K80 Return Value
269 1751989937890 GEN4_TO_CONTROLLER_LOG:GEN4_INIT_INT_LOG_PIC18F26K80 com.microchip.mplab.libs.RI4ToolsController.implementations.RI4DebugInterfaceImpl@2580ee27
269 1751989937890 GEN4_TO_CONTROLLER_LOG:GEN4_INIT_INT_LOG_PIC18F26K80 Return End

269 1751989937891 GEN4_TO_CONTROLLER_LOG:GEN4_INIT_INT_LOG_PIC18F26K80 Pre:GetInterfaceProvider
269 1751989937891 GEN4_TO_CONTROLLER_LOG:GEN4_INIT_INT_LOG_PIC18F26K80 Payload
269 1751989937891 GEN4_TO_CONTROLLER_LOG:GEN4_INIT_INT_LOG_PIC18F26K80 RI4ProgramInterface
269 1751989937891 GEN4_TO_CONTROLLER_LOG:GEN4_INIT_INT_LOG_PIC18F26K80 Payload End
269 1751989937891 GEN4_TO_CONTROLLER_LOG:GEN4_INIT_INT_LOG_PIC18F26K80 Post:GetInterfaceProvider
269 1751989937891 GEN4_TO_CONTROLLER_LOG:GEN4_INIT_INT_LOG_PIC18F26K80 Return Value
269 1751989937891 GEN4_TO_CONTROLLER_LOG:GEN4_INIT_INT_LOG_PIC18F26K80 com.microchip.mplab.libs.RI4ToolsController.implementations.RI4ProgramInterfaceImpl@191e8b0a
269 1751989937891 GEN4_TO_CONTROLLER_LOG:GEN4_INIT_INT_LOG_PIC18F26K80 Return End

269 1751989937891 GEN4_TO_CONTROLLER_LOG:GEN4_INIT_INT_LOG_PIC18F26K80 Pre:GetInterfaceProvider
269 1751989937891 GEN4_TO_CONTROLLER_LOG:GEN4_INIT_INT_LOG_PIC18F26K80 Payload
269 1751989937891 GEN4_TO_CONTROLLER_LOG:GEN4_INIT_INT_LOG_PIC18F26K80 RI4ConnectInterface
269 1751989937891 GEN4_TO_CONTROLLER_LOG:GEN4_INIT_INT_LOG_PIC18F26K80 Payload End
269 1751989937891 GEN4_TO_CONTROLLER_LOG:GEN4_INIT_INT_LOG_PIC18F26K80 Post:GetInterfaceProvider
269 1751989937891 GEN4_TO_CONTROLLER_LOG:GEN4_INIT_INT_LOG_PIC18F26K80 Return Value
269 1751989937891 GEN4_TO_CONTROLLER_LOG:GEN4_INIT_INT_LOG_PIC18F26K80 com.microchip.mplab.libs.PK4ToolsController.PK4ConnectInterfaceImpl@a64c82d
269 1751989937891 GEN4_TO_CONTROLLER_LOG:GEN4_INIT_INT_LOG_PIC18F26K80 Return End

269 1751989937891 GEN4_TO_CONTROLLER_LOG:GEN4_INIT_INT_LOG_PIC18F26K80 Pre:GetInterfaceProvider
269 1751989937891 GEN4_TO_CONTROLLER_LOG:GEN4_INIT_INT_LOG_PIC18F26K80 Payload
269 1751989937891 GEN4_TO_CONTROLLER_LOG:GEN4_INIT_INT_LOG_PIC18F26K80 RI4ControllerDiagnosticsInterface
269 1751989937891 GEN4_TO_CONTROLLER_LOG:GEN4_INIT_INT_LOG_PIC18F26K80 Payload End
269 1751989937891 GEN4_TO_CONTROLLER_LOG:GEN4_INIT_INT_LOG_PIC18F26K80 Post:GetInterfaceProvider
269 1751989937891 GEN4_TO_CONTROLLER_LOG:GEN4_INIT_INT_LOG_PIC18F26K80 Return Value
269 1751989937891 GEN4_TO_CONTROLLER_LOG:GEN4_INIT_INT_LOG_PIC18F26K80 com.microchip.mplab.libs.RI4ToolsController.implementations.RI4ControllerDiagnosticsInterfaceImpl@285f19a9
269 1751989937891 GEN4_TO_CONTROLLER_LOG:GEN4_INIT_INT_LOG_PIC18F26K80 Return End

269 1751989937891 GEN4_TO_CONTROLLER_LOG:GEN4_INIT_INT_LOG_PIC18F26K80 Pre:GetInterfaceProvider
269 1751989937891 GEN4_TO_CONTROLLER_LOG:GEN4_INIT_INT_LOG_PIC18F26K80 Payload
269 1751989937891 GEN4_TO_CONTROLLER_LOG:GEN4_INIT_INT_LOG_PIC18F26K80 ProgrammerToGo
269 1751989937891 GEN4_TO_CONTROLLER_LOG:GEN4_INIT_INT_LOG_PIC18F26K80 Payload End
269 1751989937891 GEN4_TO_CONTROLLER_LOG:GEN4_INIT_INT_LOG_PIC18F26K80 Post:GetInterfaceProvider
269 1751989937891 GEN4_TO_CONTROLLER_LOG:GEN4_INIT_INT_LOG_PIC18F26K80 Return Value
269 1751989937891 GEN4_TO_CONTROLLER_LOG:GEN4_INIT_INT_LOG_PIC18F26K80 com.microchip.mplab.libs.RI4ToolsController.implementations.ProgrammerToGoImpl@a8c3b53
269 1751989937891 GEN4_TO_CONTROLLER_LOG:GEN4_INIT_INT_LOG_PIC18F26K80 Return End

269 1751989937892 GEN4_TO_CONTROLLER_LOG:GEN4_INIT_INT_LOG_PIC18F26K80 Pre:GetInterfaceProvider
269 1751989937892 GEN4_TO_CONTROLLER_LOG:GEN4_INIT_INT_LOG_PIC18F26K80 Payload
269 1751989937892 GEN4_TO_CONTROLLER_LOG:GEN4_INIT_INT_LOG_PIC18F26K80 Status
269 1751989937892 GEN4_TO_CONTROLLER_LOG:GEN4_INIT_INT_LOG_PIC18F26K80 Payload End
269 1751989937892 GEN4_TO_CONTROLLER_LOG:GEN4_INIT_INT_LOG_PIC18F26K80 Post:GetInterfaceProvider
269 1751989937892 GEN4_TO_CONTROLLER_LOG:GEN4_INIT_INT_LOG_PIC18F26K80 Return Value
269 1751989937892 GEN4_TO_CONTROLLER_LOG:GEN4_INIT_INT_LOG_PIC18F26K80 null
269 1751989937892 GEN4_TO_CONTROLLER_LOG:GEN4_INIT_INT_LOG_PIC18F26K80 Return End

269 1751989937900 GEN4_TO_CONTROLLER_LOG:GEN4_CONNECT_INT_LOG_PIC18F26K80 Pre:EstablishCommunincations
269 1751989937900 GEN4_TO_CONTROLLER_LOG:GEN4_CONNECT_INT_LOG_PIC18F26K80 Payload
269 1751989937900 GEN4_TO_CONTROLLER_LOG:GEN4_CONNECT_INT_LOG_PIC18F26K80 com.microchip.mplab.mdbcore.PK5Tool.PK5Com@7d38335e
269 1751989937900 GEN4_TO_CONTROLLER_LOG:GEN4_CONNECT_INT_LOG_PIC18F26K80 Payload End
269 1751989937900 GEN4_TO_CONTROLLER_LOG:GEN4_CONNECT_INT_LOG_PIC18F26K80 Post:EstablishCommunincations
269 1751989937900 GEN4_TO_CONTROLLER_LOG:GEN4_CONNECT_INT_LOG_PIC18F26K80 Return Value
269 1751989937900 GEN4_TO_CONTROLLER_LOG:GEN4_CONNECT_INT_LOG_PIC18F26K80 true
269 1751989937900 GEN4_TO_CONTROLLER_LOG:GEN4_CONNECT_INT_LOG_PIC18F26K80 Return End

269 1751989937900 GEN4_TO_CONTROLLER_LOG:GEN4_CONNECT_INT_LOG_PIC18F26K80 Pre:GetFirmwareInfo
269 1751989937900 GEN4_TO_CONTROLLER_LOG:GEN4_CONNECT_INT_LOG_PIC18F26K80 Payload
269 1751989937900 GEN4_TO_CONTROLLER_LOG:GEN4_CONNECT_INT_LOG_PIC18F26K80 null
269 1751989937900 GEN4_TO_CONTROLLER_LOG:GEN4_CONNECT_INT_LOG_PIC18F26K80 Payload End
269 1751989937901 XXXX 1751989937901, Thread 269: com.Send returned false 
269 1751989937901 XXXX 1751989937901, Thread 269: execCommand: exception after writeSideChanel null

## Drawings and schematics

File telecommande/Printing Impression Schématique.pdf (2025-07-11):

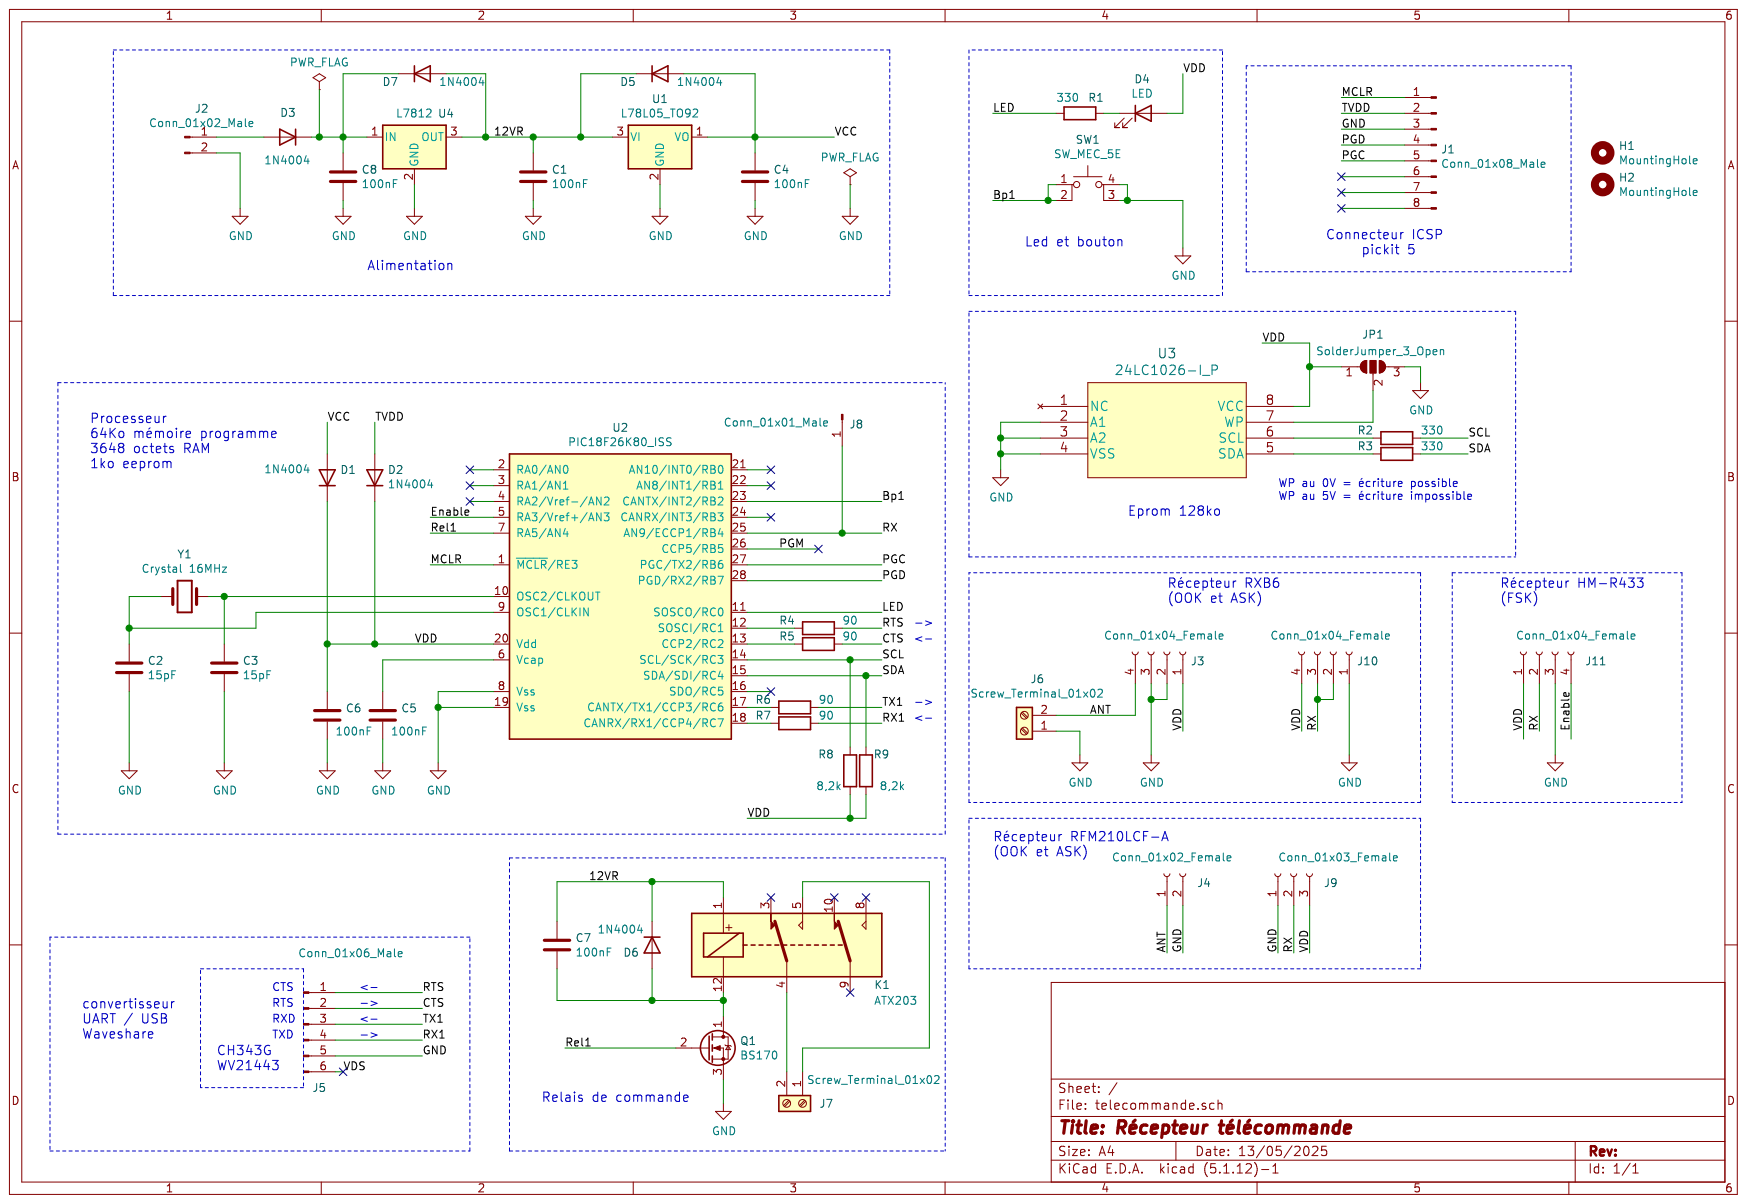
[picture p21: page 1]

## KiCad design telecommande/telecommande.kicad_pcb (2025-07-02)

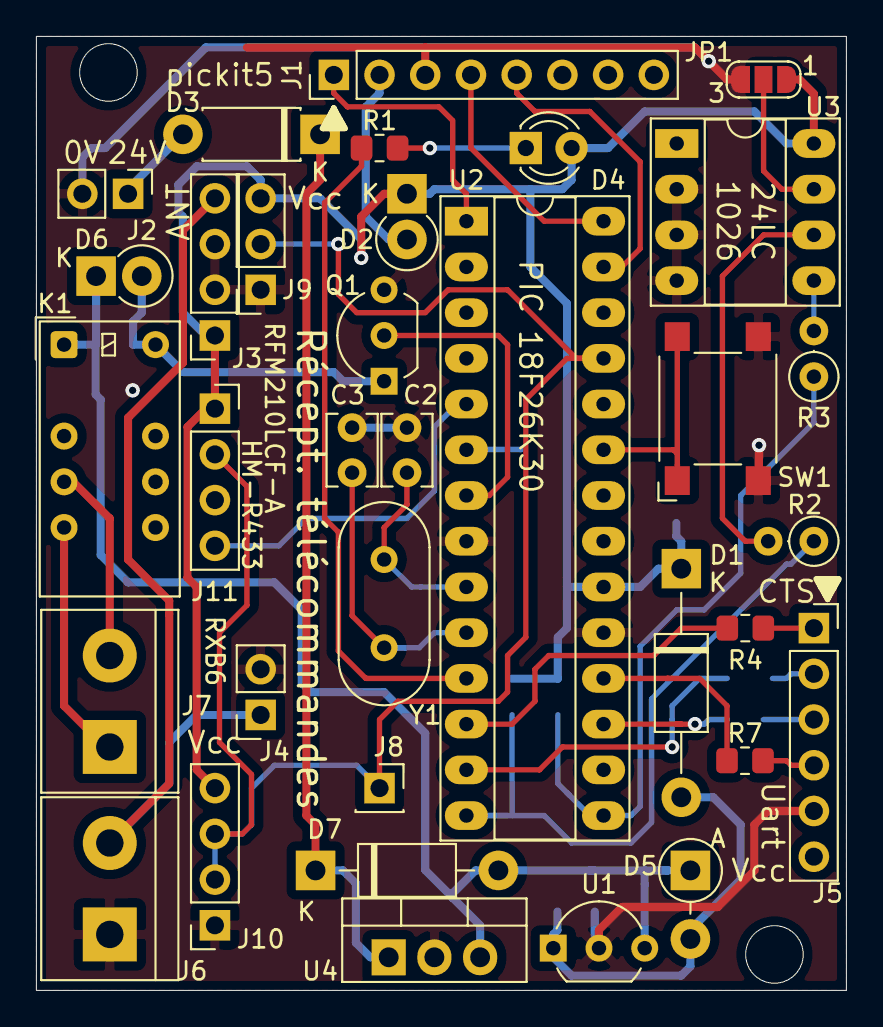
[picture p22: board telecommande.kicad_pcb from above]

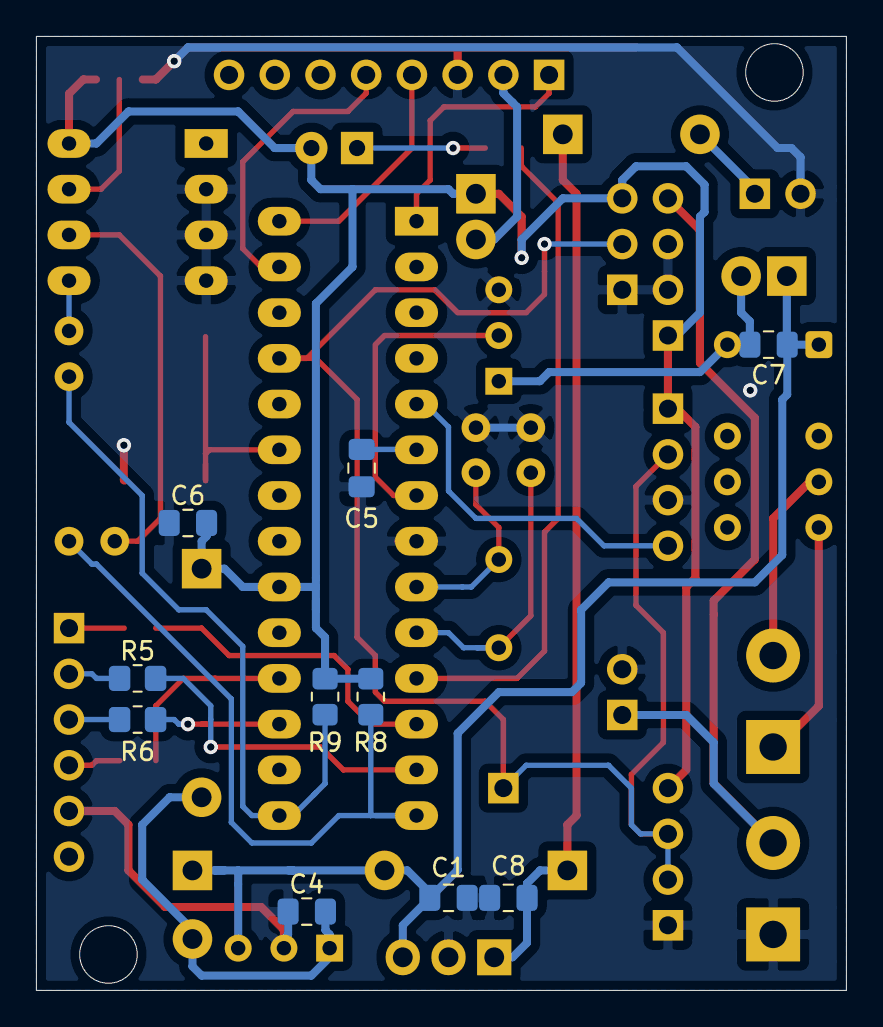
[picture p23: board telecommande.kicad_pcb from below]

Board: 2 copper layers, 45.0 x 53.0 mm, 46 parts (10 on the bottom side), 36 nets.

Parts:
C1, C4, C5, C6, C7, C8: 100nF; C_0805_2012Metric_Pad1.18x1.45mm_HandSolder
C2, C3: 15pF; C_Disc_D3.8mm_W2.6mm_P2.50mm
D1: 1N4004; D_DO-41_SOD81_P12.70mm_Horizontal
D2, D6: 1N4004; D_DO-41_SOD81_P2.54mm_Vertical_KathodeUp
D3: 1N4004; D_DO-41_SOD81_P7.62mm_Horizontal
D4: LED; LED_D3.0mm
D5: 1N4004; D_DO-41_SOD81_P3.81mm_Vertical_AnodeUp
D7: 1N4004; D_DO-41_SOD81_P10.16mm_Horizontal
H1, H2: MountingHole; MountingHole_3.2mm_M3
J1: Conn_01x08_Male; PinHeader_1x08_P2.54mm_Vertical
J2: Conn_01x02_Male; PinHeader_1x02_P2.54mm_Vertical
J3, J10, J11: Conn_01x04_Female; PinSocket_1x04_P2.54mm_Vertical
J4: Conn_01x02_Female; PinSocket_1x02_P2.54mm_Vertical
J5: Conn_01x06_Male; PinSocket_1x06_P2.54mm_Vertical
J6, J7: Screw_Terminal_01x02; TerminalBlock_bornier-2_P5.08mm
J8: Conn_01x01_Male; PinSocket_1x01_P2.54mm_Vertical
J9: Conn_01x03_Female; PinSocket_1x03_P2.54mm_Vertical
JP1: SolderJumper_3_Open; SolderJumper-3_P1.3mm_Open_RoundedPad1.0x1.5mm_NumberLabels
K1: ATX203; Relay_DPDT_Kemet_EC2
Q1: BS170; TO-92_Inline_Wide
R1: 330; R_0805_2012Metric_Pad1.20x1.40mm_HandSolder
R2, R3: 330; R_Axial_DIN0207_L6.3mm_D2.5mm_P2.54mm_Vertical
R4, R5, R6, R7: 90; R_0805_2012Metric_Pad1.20x1.40mm_HandSolder
R8, R9: 8,2k; R_0805_2012Metric_Pad1.20x1.40mm_HandSolder
SW1: SW_MEC_5E; SW_SPST_Omron_B3FS-101xP
U1: L78L05_TO92; TO-92_Inline_Wide
U2: PIC18F26K80_ISS; DIP-28_W7.62mm_Socket_LongPads
U3: 24LC1026-I_P; DIP-8_W7.62mm_Socket_LongPads
U4: L7812; TO-220-3_Vertical
Y1: Crystal 16MHz; Crystal_HC18-U_Vertical

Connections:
/12VR: C1.1, C7.1, D5.1, D6.1, D7.2, K1.1, U1.3, U4.3
/ANT: J3.4, J4.1, J6.2
/Bp1: SW1.1, SW1.2, U2.23
/CTS: J5.2, R5.1
/Enable: J11.4, U2.5
/LED: R1.2, U2.11
/MCLR: J1.1, U2.1
/PGC: J1.5, U2.27
/PGD: J1.4, U2.28
/RTS: J5.1, R4.1
/RX: J8.1, J9.2, J10.2, J10.3, J11.2, U2.25
/RX1: J5.4, R7.1
/Rel1: Q1.2, U2.7
/SCL: R2.1, R8.2, U2.14
/SDA: R3.1, R9.2, U2.15
/TVDD: D2.2, J1.2
/TX1: J5.3, R6.1
/VCC: C4.1, D1.2, D5.2, U1.1
/VDD: C6.1, D1.1, D2.1, D4.2, J3.1, J9.3, J10.4, J11.1, JP1.1, R8.1, R9.1, U2.20, U3.8
GND: C1.2, C2.2, C3.2, C4.2, C5.2, C6.2, C8.2, J1.3, J2.2, J3.2, J3.3, J4.2, J5.5, J6.1, J9.1, J10.1, J11.3, JP1.3, Q1.3, SW1.3, SW1.4, U1.2, U2.8, U2.19, U3.2, U3.3, U3.4, U4.2
unnamed: C2.1, U2.9, Y1.1
unnamed: C3.1, U2.10, Y1.2
unnamed: C5.1, U2.6
unnamed: C7.2, D6.2, K1.12, Q1.1
unnamed: C8.1, D3.1, D7.1, U4.1
unnamed: D3.2, J2.1
unnamed: D4.1, R1.1
unnamed: J7.1, K1.5
unnamed: J7.2, K1.4
unnamed: JP1.2, U3.7
unnamed: R2.2, U3.6
unnamed: R3.2, U3.5
unnamed: R4.2, U2.12
unnamed: R5.2, U2.13
unnamed: R6.2, U2.17
unnamed: R7.2, U2.18

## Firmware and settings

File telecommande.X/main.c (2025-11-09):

/* 
04/11/2025
programme décodeur télécommande protocole NICE FLOR-S / CAME / Somfy RTS / EV1527
NICE FLOR-decode_b06_niceS / CAME / Somfy RTS / EV1527 protocol receiver remote control decoder program
MPLAB X IDE v6.25
   
Processeur pic 18F26K80 
  Mémoire programme 64Ko
  Mémoire RAM 3648 octets
  Mémoire EPROM int 1ko : contient le fichier KI / contains KI file
Mémoire EPROM ext de 128Ko 24LC1026 I2C / contient le fichier de codes nice flors-s / contains nice flor-s file codes

Pour ne pas écraser l'eprom interne à chaque programmation du pic:
To avoid overwriting the internal EPROM each time the pic is programmed:
dans Option/pickit5 : Memories to programm
allow pickit5 to select memory
preserve eprom memory
memory range : 0-3ff
 
liaison UART : 9600,n,8,1 / 230400,n,8,1
Config dans MCC: 
 UART :
 aync_noninverted_sync_inverted
 DataReceive Polarity : non_inverted  
 HS mode car c'est un quartz (16MHz)
 SOSC = oscillateur secondaire, non utilisé
 FOSC = oscillateur primaire à quartz, utiisé
  LP : quartz de 32 kHz
  XT : quartz de 4 MHz
  HS : quartz >4 MHz
  
UART :             230400    115200      9600
SPBRGH1/SPBRG1 = 0x00/0x44  0x00/0x8A  0x06/0x82
la vitesse de 230400 est presque ok pour le debug, en dessous, on mesure mal avec l'affichage
éviter d'utiliser l'UART pendant l'acquisition du signal radio même en 230400 bauds, ca fausse l'acquisition.

A speed of 230400 is nearly ok for debugging ; below this speed, the measurement is poor with display on.
Avoid using the UART during radio signal acquisition, even at 230400 baud, as this will distort the acquisition.
 
Bus I2C à 400 kHz
EPROM 24LC1026 = 2x64Ko: Adresse I2C 1010 A2 A1 B RW  = 1010 0000 = 0xA0  
 
Plan d'adressage de l'eeprom interne:
Internal EEPROM mapping:
 0x000 - 0x0ff : codes KI de niceflor-s / KI codes niceflor-s
 0x100       : numéro série télécommande n=1 (32 bits) / serial #, remote 1 / low to high bytes
 0x104       : télécommande n=2 : serial #, remote 2
 0x108       : 3
 0x10C       : 4
 0x110       : 5
 0x114       : 6
 0x118       : 7
 0x11C       : 8
 0x120       : 9
 0x124       ; 10
 0x128       ; 11
 0x12c       ; 12 
 .....
 0x14c       ; 20    = (n-1) * 4 + 0x100
 .. jusque 12 télécommandes / up to 12 remotes
 
Récepteurs testés / Tested receivers :
modulations ASK et OOK / both ASK and OOK
RFM210LCF 
RXB6 : 
RXB8 : 315 MHz
RX500                   ASK   -108dBm
RFM02 (chip CMT2210LC)  OOK only

Récepteurs FSK : 
HM-R-433 ??? marche pas sur cardin  (5?) Sensibilité : -109 dBm, ne décode rien....!
RC-RFSK1-433N  Radiocontrolli (8?) Sensibilité : -118 dBm
RXB15                         (2?) Sensibilité : -108 dBm ou -118dBm suivant sources. Introuvable au détail. Unavailable on retail
Dickert HQFM433P-50           (30?) récepteur cardin "officiel" à 15 broches - works with fobloqf
1=5V 2=0V 3=ANT 10,12,15=au 5V  7,11=0V  13=PDO peak detector output, ne pas relier.  14=data
 
----------------------------------------------------------
Protocole Nice-flors (radio ASK) : protocole assez sophistiqué qui nécessite une table de 
décodage de 65535 mots, et une table de 256 octets.
Quite sophisticated protocol, requires a 65535 words decoding table and a 256 bytes table.
fonctionne avec les récepteurs RXB6 / works with receivers : RXB6 & RFM210LCF
https://github.com/Jev1337/NiceFlor-Encoder/tree/main

Le contenu de l'eprom des codes nice flor-s est ici:
the eprom-codes nice flor-s is here: (inverted words)
https://github.com/Jev1337/NiceFlor-Encoder/blob/main/C%20Version/ArduinoC/codes.h
ou dans ce projet : codes.bin

En eprom interne / in internal eprom
un bloc de 256 octets : nice_flor_s_table_ki[256]
ki.bin 
 
 description du code:
  code roulant de 52 bits / 52 bits rolling code
  1 bit silence de 18500 µs (37 x 500µs)
  2 bits début de 1500 µs  (3 x 500 µs)
  les bits du message:
  1 bit à 1 est constitué de deux signaux :  500µs puis 1000µs
  1 bit à 0 est constitué de deux signaux : 1000µs puis  500µs
  1 bit 1500 µs de fin
 
exemples de codes
transmis par télécommande 52 bits / 7 octets décodés brut (b0 b6)
remote transmits 52 bits / 7 bytes raw decoded (b0-b6)
  E3052 39A7FA15 Decode=1/CF/AD/C6/58/5/EA
  E2052 39A7FA15 Decode=1/DF/AD/C6/58/5/EA
  E5052 39A7FA15 Decode=1/AF/AD/C6/58/5/EA
  E4052 39A7FA15 Decode=1/BF/AD/C6/58/5/EA

B2-B3 est le code courant envoyé par la télécommande. Ce code se trouve dans l'eprom 128Ko. Son index sert de clé de décodage.
B2-B3 is the current code sent by the remote device. This code is within the 128kb eprom. The code index is the decoding key.

7 octets décodés bruts / numéro de série / bouton / index code / répétition
(b0-b6)                  télécommande
7 raw decoded bytes    / serial remote  / button / index code / repeat
ok  1/db/52/cc/4c/11/fe/ Serial=0295C827,Bouton=1,Code=1946,repete=3
ok  1/c8/38/e7/cf/92/7d/ Serial=0295C827,Bouton=1,Code=1947,repete=2
ok  2/c3/61/62/14/49/a6/ Serial=0295C827,Bouton=2,Code=1948,repete=1
ok  2/83/61/62/14/49/a6/ Serial=0295C827,Bouton=2,Code=1948,repete=5

Exemples d'erreurs / Error examples :
EZ41     : bit start ou stop mal placé, inattendu en position 41
         : unexpected start or stop bit in position 41
EF101    : erreur de longueur de bit reçu pendant les données en position 101
         : length duration bit error during datas in position 101
EA=1250  : erreur A de symétrie dans le motif des données (rencontré 500/500 µs au lieu de 500/1000µs)
         : 1250 est la valeur du TMR0
         : error A symétrical frame in data (encountered 500/500 µs instead of 500/1000µs)
         : 1250 is the TMR0 value
EB=2500  : erreur B de symétrie dans les données (rencontré 1000/1000 au lieu de 1000/500µs)
         : error B symétrical frame in data (encountered 1000/1000 µs instead of 1000/500µs)

Décodage correct / correct decoding :
NumSer=0295C827,Bouton=1 T1 ok  <-- télécommande 1 reconnue car enregistrée / remote 1 recognized
NumSer=027588B4,Bouton=2 T0     <-- télécommande 0 reçue signifie inconnue / remote 0 means unknown

documentation télécommandes:
https://www.cliffsnotes.com/study-notes/23860179 
 
Pour Nice flors: pour lire les 128ko de l'eprom ext (quand on cherche le code de décodage), il faut jusque 7s , trop long pour un décodage.
donc on utilise l'ancien code transmis (par télécommande) pour "prévoir" le suivant qui est incrémenté de 1, qui doit
se trouver dans les 128 octets suivants.
About nice flors: reading the 128kB of the ext eprom (when fetching the decoding code) takes up to 7s, too long for decoding.
So we use the previous transmitted code (per remote) to "predict" the next one, which is incremented by 1, 
and have to be inside the next 128 ones.
  
---------------------------------------------------
Protocole CAME (radio OOK) protocol: 
fonctionne avec les récepteurs / work with receivers : RXB6 & RFM210LCF-A 
Code fixe 26 bits / Static 26 bits code
https://github.com/jehy/arduino-came-reader
https://github.com/psa-jforestier/rtl_433_tests/tree/master/tests/Came/TOP432
https://github.com/merbanan/rtl_433/issues/1452

-------------------------------------------------
Protocole Somfy RTS
fonctionne avec les récepteurs / work with receivers : RXB6 & RFM210LCF-A 
Code roulant simple de 56 bits.
Simple 56 bits rolling code.
https://github.com/Legion2/Somfy_Remote_Lib
https://pushstack.wordpress.com/somfy-rts-protocol/

---------------------------------------------------
Protocole (radio FM) CARDIN S449 :
utiliser le récepteur Dickert HQFM433P-50
cardin S449 utilise le protocole FSK /  cardin S449 uses the FSK protocol
64 bits keelok
On ne prend en compte que le numéro de série de la télécommande pour le décodage, pas le compteur qui est codé.
We just check the serial remote for decoding, not the encoded counter.
https://cargeek.live/docs/Sec_Analysis_Garage_Door_XXxiOwB.pdf
Cardin    Serial=0063F2DA=6550234 Bouton=2 
6550234 est le numéro de série de la télécommande en décimal, écrit sur son l'étiquette.
6550234 is the remote serial number in decimal, printed on the tag of the remote.

---------------------------------------------------
Protocole FoBloqf (FM) de rfsolutions.co.uk non documenté
utiliser le récepteur Dickert HQFM433P-50
Utilise un Keeloq - pas finalisé
utiliser le récepteur Dickert HQFM433P-50
Utilise un extra bit

--------------------------------------------------  
Protocole EV RT1527 FP1527 (télécommande AK-FS02A) : code fixe à 24 bits
https://w.electrodragon.com/w/images/7/7b/RT1527E.pdf
Entete / numéro de série à 20 bits / D0 D1 D2 D3 (boutons)
Sync  = Haut (1) pendant 32 cycles, Bas (0) pendant 991 cycles
Bit 0 = Haut (1) pendant 32 cycles, Bas (0) pendant 96 cycles
Bit 1 = Haut (1) pendant 96 cycles, Bas (0) pendant 32 cycles
transmission LSB en premier (décaler à droite à la réception)

--------------------------------------------------
Protocole SCT2260
code fixe de 12 bits
chronogramme :
1 silence de 15100 µs
court long  court long  = bit 0
long  court long  court = bit 1
court long  long  court = bit flottant
 
 
Pour apprendre une nouvelle télécommande : 
  appui court sur le bouton (la led clignote) et activer la télécommande dans les 5s.
Pour supprimer toutes les télécommandes :
  appui long de 5s : la led s'allume 3s.

To learn a new remote :
  short press (led is blinking) then press on remote button within 5s.
To delete all remotes ;
  5s long press : led lights up for 3s.

Les télécommandes Somfy (certaines) et Cardin ont un bouton de programmation qui permettent de mémoriser
un bouton d'une télécommande déja connue à un récepteur associé. Ce programme utilise cette fonction,
mais prend en compte tout signal suivant se présentant et peut constituer une faille de sécurité.
Cette fonctionnalité peut être dévalidée.
Ceci est utile si le récepteur est encastré et on ne peut pas appuyer sur le bouton d'ajout d'une nouvelle télécommande.
(modeProg).
Some Somfy and Cardin remotes have a programm button that allows to memorize unknown button remote to an 
already linked receiver. This program uses this feature, but also takes into account any subsequent signal that may appear,
and might be a security failure. This feature can be disabled.
This is useful if the receiver is recessed and the button to add a new remote control can't be pressed.
 

*/

#include "mcc_generated_files/system/system.h"
#include "string.h"
#include "stdlib.h"

#define debugxmodem 0
#define francais    1    // choisissez votre langue
#define english     0    // choose your language

#define led     RC0     // sortie
#define rts     RC1     // sortie - not used : UART protocole rts/cts - vers CTS PC : bloque l'envoi du PC
#define cts     RC2     // entrée - not used : UART protocole rts/cts - de PC : bloque l'envoi vers le PC
#define enable  RA3     // enable récepteur HM-R-433 ou autre qui ont une entrée enable
#define rel1    RA5     // commande bobine du relais / relay coil command
#define MAX_COMMAND_LEN       8U
#define LINEFEED_CHAR         (uint8_t)'\n'
#define CARRIAGERETURN_CHAR   (uint8_t)'\r'
#define Eprom24lc1026 0xA0 >>1     // Adresse I2C - BO en bit 1 (avant décalage) pour le bloc 0/1
#define Eprom24wc16 0xA0 >>1
#define maxtel  20       // nombre de télécommandes maxi

#define KeeLoq_NLF    0x3A5C742E  // clé de 32 bits
#define bit(x,n) (((x)>>(n))&1)
#define g5(x,a,b,c,d,e)	(bit(x,a)+bit(x,b)*2+bit(x,c)*4+bit(x,d)*8+bit(x,e)*16)
// clé de l'agorithme keeloq 64bit LSB-first
uint8_t key[] = {0x56,0x4a,0xbc,0x07,0x57,0x1e,0x62,0x94};

// CAME éléments radio / radio items
// 433,920 MHz  modulation HF AM-OOK (tout ou rien AM)
const uint16_t silenceC=29690;  // 14845 µs silent
const uint16_t debutbitC=2660;  // 1280 µs start
const uint16_t bit0C=640;       // 320 µs  
const uint16_t bit1C=1280;      // 640 µs
const uint16_t toleranceC=170;
// calculées:
const uint16_t silenceC_M=silenceC-toleranceC;
const uint16_t silenceC_P=silenceC+toleranceC;
const uint16_t debutbitC_M=debutbitC-toleranceC;
const uint16_t debutbitC_P=debutbitC+toleranceC;
const uint16_t bit0C_M=bit0C-toleranceC; 
const uint16_t bit0C_P=bit0C+toleranceC;
const uint16_t bit1C_M=bit1C-toleranceC; 
const uint16_t bit1C_P=bit1C+toleranceC;
const uint16_t coupureC=(bit0C+bit1C)/2;

// CARDIN nécessite un récepteur FM-FSK
// 433,920 MHz requires a FM-FSK receiver
const uint16_t silenceD=33000;  // 34000 16520µs; 
const uint16_t debutbitD=8020;  // 4000µs
const uint16_t bit0D=850;       // 856 730 µs (officiel 400µs)   
const uint16_t bit1D=1600;      // 1560 500 µs (officiel=800µs)
const uint16_t toleranceD=350;  // 250 grande dispersion sur cardin
// calculées:
const uint16_t silenceD_M=silenceD-toleranceD;
const uint16_t silenceD_P=silenceD+toleranceD;
const uint16_t debutbitD_M=debutbitD-toleranceD;
const uint16_t debutbitD_P=debutbitD+toleranceD;
const uint16_t bit0D_M=bit0D-toleranceD; 
const uint16_t bit0D_P=bit0D+toleranceD;
const uint16_t bit1D_M=bit1D-toleranceD; 
const uint16_t bit1D_P=bit1D+toleranceD;
const uint16_t coupureD=(bit0D+bit1D)/2;

// Fobloqf pas encore traité, nécessite un récepteur FM-FSK
// 433,920 MHz requires a FM-FSK receiver
const uint16_t silenceF=6800;   //3x3400µs silence
const uint16_t debutbitF=3140;  // start 1570µs
const uint16_t bit0F=790;       // 400 µs     
const uint16_t bit1F=1570;      // 800 µs 
const uint16_t toleranceF=150;
// calculées:
const uint16_t silenceF_M=silenceF-toleranceF;
const uint16_t silenceF_P=silenceF+toleranceF;
const uint16_t debutbitF_M=debutbitF-toleranceF;
const uint16_t debutbitF_P=debutbitF+toleranceF;
const uint16_t bit0F_M=bit0F-toleranceF; 
const uint16_t bit0F_P=bit0F+toleranceF;
const uint16_t bit1F_M=bit1F-toleranceF; 
const uint16_t bit1F_P=bit1F+toleranceF;
const uint16_t coupureF=(bit0F+bit1F)/2;
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
int main(void)
{
  SYSTEM_Initialize();
  enable=0;
  rel1=0;   // relais non collé
  erreur=0;
    
  // If using interrupts in PIC18 High/Low Priority Mode you need to enable the Global High and Low Interrupts 
  // If using interrupts in PIC Mid-Range Compatibility Mode you need to enable the Global and Peripheral Interrupts 
  // Use the following macros to: 
  // affectation des routines d'interruption
  //INT0_SetInterruptHandler (myINT0); 
  // INT1_SetInterruptHandler (myINT1); 
    
  // Enable the Global Interrupts 
  //INTERRUPT_GlobalInterruptEnable(); 

  // Disable the Global Interrupts 
  //INTERRUPT_GlobalInterruptDisable(); 
  // Enable the Peripheral Interrupts 
  //INTERRUPT_PeripheralInterruptEnable(); 

  // Disable the Peripheral Interrupts 
  //INTERRUPT_PeripheralInterruptDisable(); 

  ANCON0=0;              // on n'utilise pas l'AD - don't need AD
  ANCON1=0;              // sinon RB4 ne marche pas - otherwise RB4 won't work
    
  RCONbits.IPEN=1;       // priorité IRQ - IRQ priority
    
  INTCON2bits.RBPU=0;    // valide les résistances de pullup sur tout le port B en entrée pour BP1 - enable pull up resistor on port B
  INTCON2bits.RBIP=1;    // Configure comme priorité haute - high priority
  
  INTCONbits.RBIF=0;     // raz flags - reset flags   
  INTCONbits.RBIE=1;     // valide l'irq IOC  - enable IOC IRQ
  INTCONbits.GIEH=1;     // priorité haute - high priprity
  INTCONbits.TMR0IF=0;   // raz indicateur tmr0 déborde - reset tmr0 overflow flag
  INTCONbits.TMR0IE=1;   // valide irq timer 0 - enable timer 0 irq
         
  IOCBbits.IOCB4=1;      // IOC sur B4 
    
  pvitesse=1;
  if (pvitesse==0) {SPBRGH1=0x06;SPBRG1=0x82;}  // 9600 bauds pour transfert xmodem
  if (pvitesse==1) {SPBRGH1=0x00;SPBRG1=0x44;}  // 240400
    
  // réglage de la prédivision par (2)=8 du timer 0 ce qui permet de mesurer le signal NiceFlorS de 18888µs
  // predevider by (2)=8
  T0CON = (2 << _T0CON_T0PS_POSN)    // T0PS  0=/2 1=/4  2=/8 3=/16 4=/32 5=/64 6=/128 7=/256 1=/4
        | (0 << _T0CON_PSA_POSN)     // PSA=0 utilise le prédiviseur
        | (1 << _T0CON_T0SE_POSN)    // T0SE Increment_hi_lo
        | (0 << _T0CON_T0CS_POSN)    // T0CS FOSC/4
        | (0 << _T0CON_T08BIT_POSN)  // T08BIT 16-bit
        | (1 << _T0CON_TMR0ON_POSN); // TMR0ON enabled
   
  #ifdef francais
  UART1_WriteString("Recepteur telecommande Nice FLOR-s / CAME / Somfy RTS / EV1527\r\n");
  UART1_WriteString("F1IWQ 2025\r\n");
  #endif  
  #ifdef english
  UART1_WriteString("Remote receiver for Nice FLOR-s / CAME / Somfy RTS / EV1527\r\n");
  UART1_WriteString("F1IWQ 2025\r\n");
  #endif  
   
  led=0;
  menu();
  led=1;
  
  // clignotement led au démarrage - blinking led at start up
  for (i=1;i<10;i++)
  {
    __delay_ms(100);
    led=0;
    __delay_ms(100);
    led=1;
  }
   
  debug=0 ; 
  
  TMR0_Start();          // démarre le timer 0 - starts timer 0
  INTCONbits.GIE=1;      // valide les irq - enable IRS
   
  i=lit_eprom_int(0);
  if (i!=0x21) 
  {
    #if francais
    printf("***Erreur l'eprom interne ne contient pas le bon fichier***\r\n");  
    #endif  
    #if english
    printf("***Error internal eprom has wrong values***\r\n");  
    #endif  
  }
  
  lit_eprom_ext(0);
  i=i2cread[0];
  if (i!=3) 
  {
    #if francais
    printf("***Erreur l'eprom externe ne contient pas le bon fichier***\r\n");  
    #endif  
    #if english
    printf("***Error external eprom has wrong values***\r\n");  
    #endif
  }
          
  enable=1;  // valide le récepteur HM R 433

  while(1)
  {
    
    /* essai rts
    rts=1;
    __delay_ms(200);
    rts=0;
    __delay_ms(200);
        
    // essai cts
    //if (cts==1) led=1; else led=0;
    */
      
    if (!RB2) // bouton appuyé
    {
      __delay_ms(1);
      tpsbouton++;
      // appui long sur bouton
      // button long press
      if (tpsbouton>5000) //5s
      { 
        led=0;
        tpsbouton=0;
        #if francais
        printf("Effacement toutes telecommandes\r\n");
        #endif
        #if english
        printf("Discarding all remotes\r\n");
        #endif
        for (crc=0x100;crc<=0x100+(4*maxtel);crc++)  // 10 télécommandes = 4x10 = 0x28
        {
          ecrit_eprom_int(crc,0xff);
        }    
        __delay_ms(1000);
        led=1;
        while (!RB2);             // attendre relache bouton - wait button release  
      }
    }  
      
    // Appui court du bouton
    // button short press
    if ((!AncBp) && (RB2) && (tpsbouton>200) && (tpsbouton<1000))
    {
      tpsvalidetelecom=50000;
      #if francais
      printf("Attente nouvelle telecommande\r\n");
      #endif
      #if english
      printf("Waiting for new remote\r\n");
      #endif  
    }  
        
    if (tpsvalidetelecom!=0)
    {
      tpsvalidetelecom--;  
      if ((tpsvalidetelecom % 1000)==0) led=!led;
      if (tpsvalidetelecom==0) 
      {
        modeProg=LOW;
        printf("Abandon memorisation\r\n");
        led=1;
      }
    }
       
       
    AncBp=RB2;   
    if (RB2) tpsbouton=0;  
        
    if (!recu) UART_ProcessCommand();  // si pas reçu télécommande, traiter l'uart - if not remote received, process uart
     
    if (aff_enr) affiche_enregistrement();
     
    // télégramme radio reçu de la télécommande depuis routine IOC, le décoder
    // radio remote received from IOC routine, start decoding
    if (recu && (code!=0))
    {
      recu=LOW;
      INTCONbits.GIE=0;      // interdit les IRQ pour éviter interférence avec la variable durée pendant l'affichage
      if (debug==2)
      {
        affiche_enregistrement();      // affiche le tableau des bits et leur durée 
      }
      if (protocole==prot_niceflors)
      {    
        if (debug>=1) {Affiche(code);printf(" ");} 
        if (decode_nice_b0b6())  // décode le code en b0 b6
        // si B0 B6 sont valides - if b0 b6 are valid
        {        
          decode_b06_nice(); // décode B0 B6 et extrait le numéro de série, bouton etc
          traitementCode();  // faire le traitement - compute the code
        }
      }
      if (protocole==prot_came)
      {
        serial=code;
        printf("Came      Serial=");Affiche4(code);
        traitementCode();
      }
      if (protocole==prot_somfy)
      {              
        if (decode_somfy()==HIGH)
        {
          printf("Somfy RTS Serial=");Affiche4(serial);
          printf(" Bouton=%x",bouton);
          traitementCode();  
        }
      }  
      if (protocole==prot_cardin)
      {
        decode_cardin();
        if (serial!=0)
        {
          printf("Cardin    Serial=");Affiche4(serial);printf("=%lu",(uint32_t)serial);
          printf(" Bouton=");
          if (bouton<=4) printf("%x ",bouton);
            else printf("P ");
        
          traitementCode();
        }
      }
      if (protocole==prot_fobloqf)
      { 
        printf("Fobloqf    Serial=");
        decode_fobloqf();
        if (serial!=0)
        {
        //if (decode_fobloqf()==HIGH) printf("Fobloqf      code=");Affiche(code);
        //traitementCode();
        }
      }
      if (protocole==prot_1527)
      { 
        printf("EV1527     Serial=");
        if (serial!=0)
        {
          decode_1527();
          traitementCode();
        }
      }
      
      if (protocole==prot_2260) 
      {
        printf("SCT2260     Serial=");
        decode_2260();
        if (serial!=0)
        {
          traitementCode();
        }
      }
          
      NbreBits=0;
      INTCONbits.GIE=1;      // valide les IRQ
    } 
  }    
}

// test __EEPROM_DATA(0x01, 0x02, 0x03, 0x04, 0x05, 0x06, 0x07, 0x08);
